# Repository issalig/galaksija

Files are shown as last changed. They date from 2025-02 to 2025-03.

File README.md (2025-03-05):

# galaksija
My building of Galaksija computer (thanks a lot Vlado Vince!)

- Case [(link)](https://github.com/issalig/galaksija/tree/main/case)
  - It contains scad files for the enclosure and the keys. [(base)](https://github.com/issalig/galaksija/blob/main/case/galaksija_case_base.stl) [(top)](https://github.com/issalig/galaksija/blob/main/case/galaksija_case_top.stl) [(keys)](https://github.com/issalig/galaksija/blob/main/case/galaksija_keys.stl)
  - The enclosure can be printed in 4 parts in order to fit in normal printers (aka Ender3)
  - Keys include also an stabilizer for space bar, you can print keys with letters on it or whithout it ans use stickers [(link)](https://github.com/issalig/galaksija/blob/main/case/galaksija_letters.pdf). Of course the script to generate it is available [(link)](https://github.com/issalig/galaksija/blob/main/case/galaksija_letters.py)
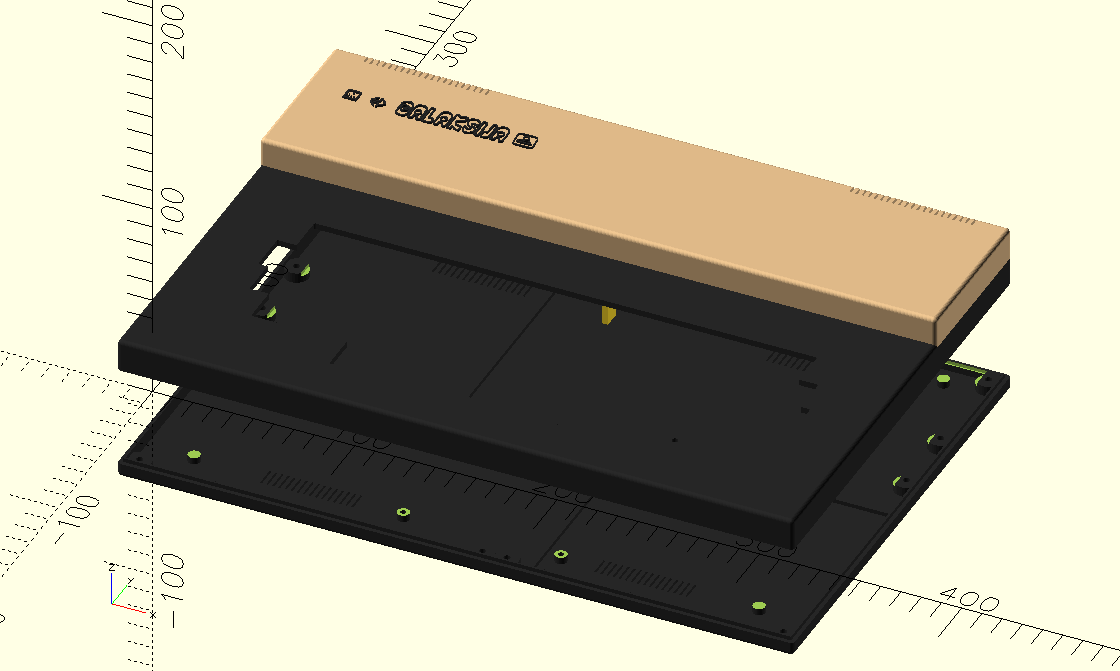
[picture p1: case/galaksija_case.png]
galaksija case
  
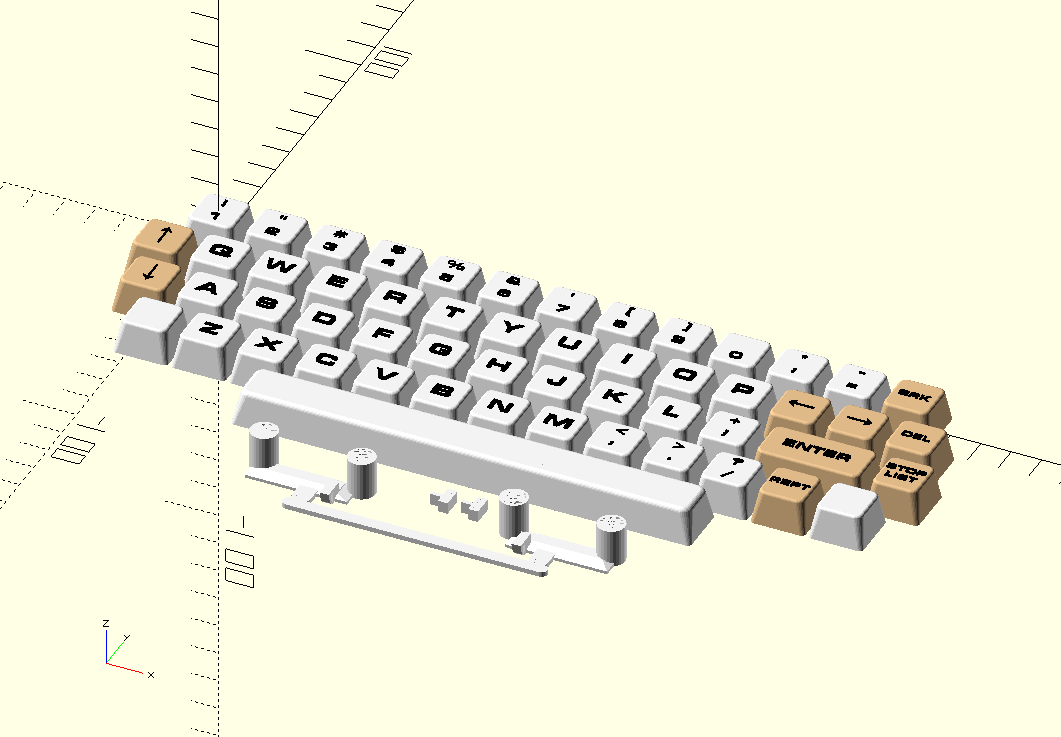
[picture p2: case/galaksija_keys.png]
galaksija keys
  
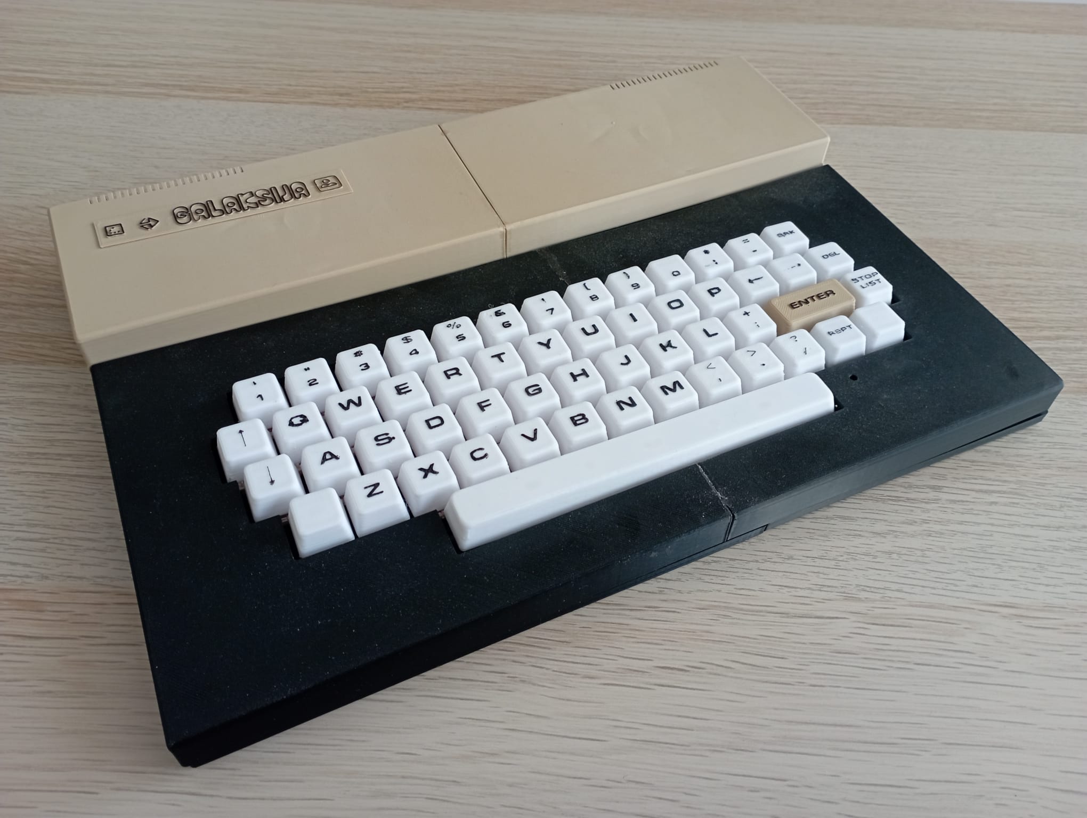
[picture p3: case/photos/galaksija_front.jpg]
galaksija front
  
  
- HW  [(link)](https://github.com/issalig/galaksija/tree/main/hw)
  - In order to build it follow instructions from https://github.com/mejs/galaksija
  - I have used v2 pcb which supports cherry switches (https://cdn.hackaday.io/files/6059259228256/Galaksija%20Outputs.zip) and you can get switches (70 pcs) from here (https://aliexpress.com/item/1005006396423418.html)
  - I use a Z80 that supports 20Mhz (not needed of course) Z84C0020PEC
  - I have used 27C512 for the ROMs instead of 2732 in a Manhattan style.
    - You just need add some wires like in the diagram and replicate the rom file.
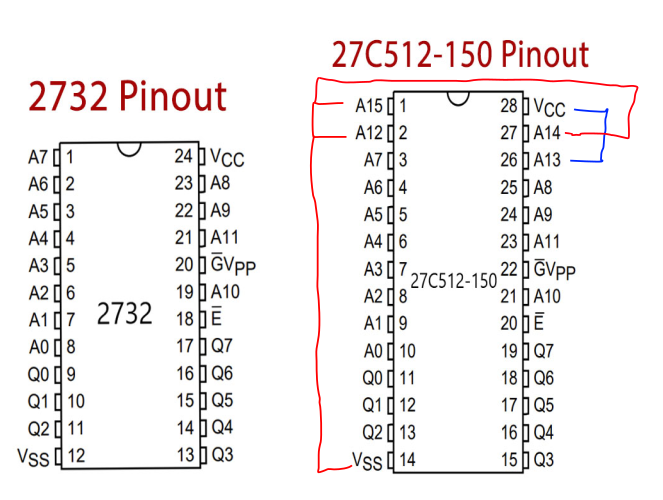
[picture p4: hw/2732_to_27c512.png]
adapter
    
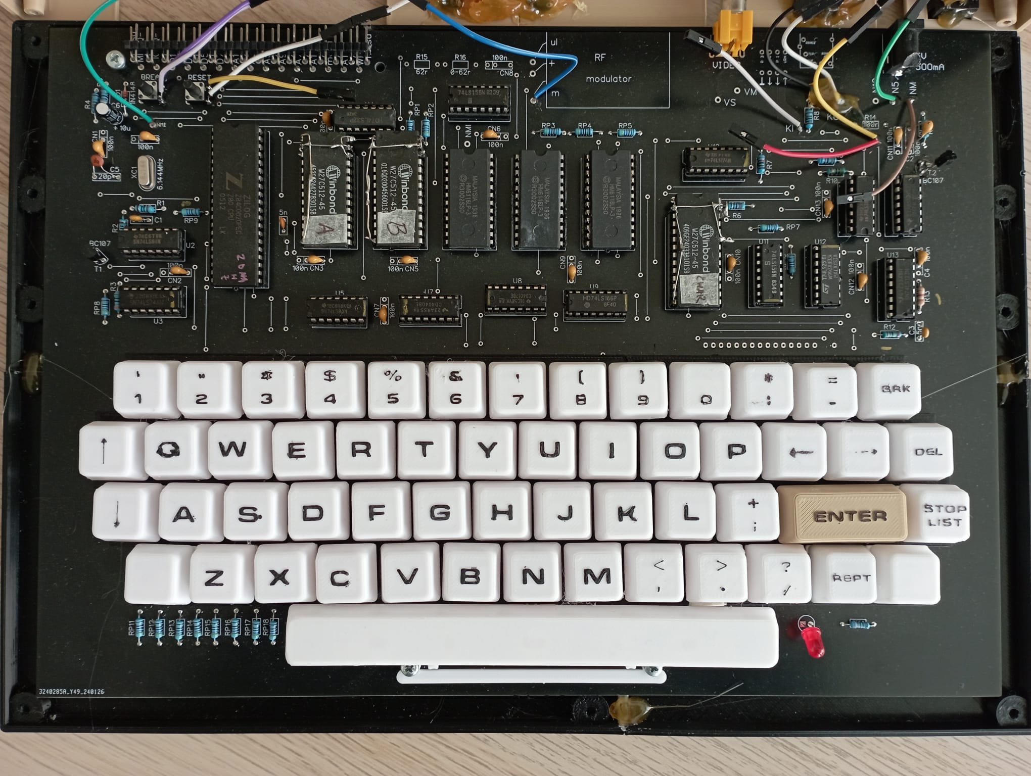
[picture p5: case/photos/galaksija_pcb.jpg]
pcb
    
    - Plan b: Get an adapter such as https://www.ukvac.com/forum/threads/2708-2716-2732-adapter-to-27512-eeprom.67258/
  - Get authentic ICs or you will have problems and a lot of "fun".
  - I have wired BRK, NMI and Reset and connected to buttons on the back side.
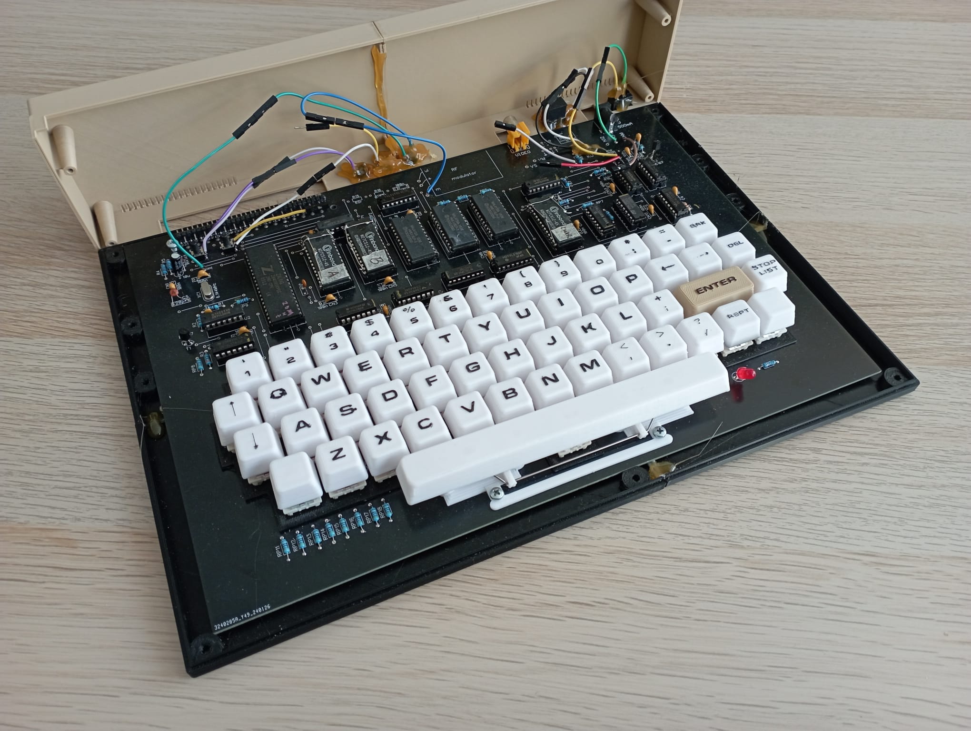
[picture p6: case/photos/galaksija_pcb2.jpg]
pcb2
    
  - Audio connections go to KI and KM
  - C2 is 1 uF (105)
  - Capacitor next to Z80 is 3.3 nF (332)

- ROMS [(link)](https://github.com/issalig/galaksija/tree/main/roms)
  - **Assembly** files for ROM A, B and C !!!!!
  - I am using ROM A [(v29 B autostart)](roms/original/ROM_A_with_ROM_B_init_ver_29.bin)
    - You can check it from your Galaksija with
      ```basic
      DUMP &0037,1
      1D (for version 29)
      DUMP &03F9,1
      CD 00 10 (call $1000 for version 29)
      ```
  - For ROM B, I use normal [(ROM_B)](roms/original/ROM_B.bin)
    - Check yours with
      ```basic
      DUMP &1024,1
      0C (for ROM B normal)
      ```          
  
- SW (TO-DO)
  - Document GTP format (WIP)
  - To load SW I got best results with a laptop. Mobile phone seem to have lower signal voltage and did not work.
 
- Other links
  - https://qsl.net/yt2fsg/galaksija/galaksija_clone.html
  - https://www.специалист-пк.рф/Galaksija/index6.html
  - https://8bitchip.info/galaksija/galaksija/schemes/GalaksijaPlus.pdf
  - https://emulator.galaksija.org/MagScans/index.html
  - https://github.com/YagoTudela/Galaksija_Plus/blob/main/SoundGenerator/SoundGeneratorPVV_01.png

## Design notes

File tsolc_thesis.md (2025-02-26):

This document is a transtlation from slovene to english from the thesis of Tomaž Šolc (https://web.archive.org/web/20240114192751/https://www.tablix.org/~avian/blog/papers/tomaz_solc_replika_mikroracunalnika_galaksija.pdf).

A presentation covering the topics of this thesis can be found in https://fahrplan.events.ccc.de/congress/2012/Fahrplan/attachments/2250_prezentacija.pdf

Another presentation in slovenian is found at https://web.archive.org/web/20230803180502/https://www.tablix.org/~avian/blog/articles/talks/mikroracunalnik_galaksija.pdf

---

# Replica of the Galaksija Microcomputer

**Tomaž Šolc**  
**Mentor:** Professor Dr. Tadej Tuma  

**University Diploma Thesis**  
**University of Ljubljana**  
**Faculty of Electrical Engineering**  

**Ljubljana, 2007**  

---

### **Abstract**  

Due to various reasons, a shortage or even complete absence of detailed documentation for older microprocessor systems is common today. Because of this, reverse engineering is often required, and understanding the design practices and methods from the era in which the system was created is essential for its success.  

**Galaksija** is a Yugoslavian home microcomputer from the 1980s, which holds historical significance. Due to its publication in magazines, part of the hardware documentation and a large collection of software, including the operating system, have been preserved to this day. As a typical yet relatively simple microprocessor system from that time, **Galaksija** provides an accessible insight into the design techniques used in that period.  

This thesis first reconstructs the documentation of **Galaksija**’s hardware architecture based on preserved schematics and reverse engineering of the software. This documentation is then used to design and build a **replica of Galaksija**—an electronic circuit built with modern components, which remains software-compatible with the original microcomputer and runs the original operating system.  

The creation of the replica also served as a foundation for documenting peculiarities in the implementation of the original electronic circuit. Furthermore, a working replica was used as a tool to analyze the programming techniques employed in the development of Galaksija’s operating system. The purpose of this documentation is to facilitate similar projects aimed at restoring microprocessor systems from this era.  

Additionally, this work includes the development of software tools for reverse engineering Z80 machine code and a development environment for the Galaksija architecture.  

**Keywords:** Galaksija, microcomputers, microprocessor systems, operating system, reverse engineering  

### **Acknowledgments**

I would like to express my gratitude to my mentor, Prof. Dr. Tadej Tuma, for his support in the preparation of this thesis.

I would like to thank my parents and my sister Barbara for their support and help during critical moments. My mother for her scientific perspective on the world and my father, who served as a role model for me in the study of electronics.

I would like to thank Mr. Jože Stepan for his assistance in gathering documentation and preserved articles about the Galaksija, for the creation of the printed circuit board, and last but not least, for the interesting conversations about old computer and electronic equipment.

I would also like to thank Tomaž Kac for his collection of preserved software for the Galaksija and for occasional hints during the exploration of the Galaksija's functionality.

I would like to thank Prof. Mateja Cvelbar for proofreading this work.

Finally, I would like to thank the other members of the Kiberpipa Computer Museum team, who allowed me access to the hidden parts of old computers and whose interest in the Galaksija was actually the reason for the creation of this thesis.

---

### **Index**
[1 Introduction](#1-introduction)
 - 1.1 Galaksija
 - 1.2 Motivation
 - 1.3 Objectives

[2 Hardware Architecture](#2-hardware-architecture)
 - 2.1 Use of Address Space
 - 2.2 Peripherals
 - 2.2.1 Keyboard
 - 2.2.2 Tape Interface
 - 2.2.3 Latch
 - 2.3 Control of the A7 Line for RAM
 - 2.4 Video Signal Generation
 - 2.4.1 Synchronization
 - 2.4.2 Character Generator
 - 2.4.3 Video Driver
 - 2.4.4 Shift Register

[3 New Galaksija](#3-new-galaksija)
 - 3.1 Digital Section
 - 3.1.1 Microprocessor and Memory
 - 3.1.2 Address Decoder
 - 3.1.3 Keyboard
 - 3.1.4 Clock Divider
 - 3.1.5 Shift Register
 - 3.1.6 Interrupt Synchronization
 - 3.2 Analog Section
 - 3.2.1 Power Supply
 - 3.2.2 Oscillator
 - 3.2.3 Reset Circuit
 - 3.2.4 Composite Video
 - 3.2.5 Tape Interface

[4 Specifics of the Original Galaksija Circuit](#4-Specifics-of-the-Original-Galaksija-Circuit)
 - 4.1 Use of Undocumented Microprocessor Features
 - 4.1.1 First Memory Cell
 - 4.1.2 Second Memory Cell
 - 4.2 Microprocessor Bus Wiring
 - 4.3 Keyboard Wiring
 - 4.4 Use of the R Register

[5 Specifics of the Operating System](#5-specifics-of-the-operating-system)
 - 5.1 Multilingual Program Code
 - 5.2 Multilingual Data Structures
 - 5.3 Organization of Program Code
 - 5.4 Use of Processor Registers
 - 5.5 Processor Stack
 - 5.6 Storing Data on Tape

[6 Conclusion](#6-conclusion)

[Bibliography](#bibliography)

[Appendix](#appendix)
 - A Voltage Inverter
 - B Calculation of the Pulse Amplifier
 - C Floating-Point Numbers

## **1. Introduction**
[Up](#Replica-of-the-Galaksija-Microcomputer) [Previous](#Index) [Next](#2-hardware-architecture)

### **1.1 Galaksija**

**Galaksija** is a home microcomputer designed in 1983 by **Voja Antonić**. Similar to other microcomputers developed in former Yugoslavia at the time, **Galaksija** was intended as a domestic alternative to foreign microcomputers produced by **Sinclair Research** (Sinclair ZX81, Sinclair ZX Spectrum) and **Commodore Business Machines** (Commodore 64). These foreign microcomputers, although highly sought after, were difficult to obtain legally due to strict import restrictions on Western technology and their relatively high prices[^1].

To make the computer as affordable as possible and accessible to the widest range of people, its electronic circuitry was designed to be as simple as possible, including only components that were either readily available in electronic stores at the time or could be easily imported from neighboring countries. Since cost reduction was the highest priority in its design, many compromises had to be made in hardware. For example, the computer's operation depends on certain undocumented features of the microprocessor, along with other design choices that would be unacceptable in modern systems. The development of system software was also heavily influenced by the goal of keeping hardware costs low.

A comparison of **Galaksija**’s capabilities with similar foreign and domestic microcomputers from the same era is shown in **Tables 1 and 2**.

Initially, **Galaksija** was intended for self-assembly. To facilitate this, the designer, with the assistance of editor **Dejan Ristanović**, published a complete guide on how to build it in a **special edition of the magazine Galaksija**, released in January 1984 [^2]. This publication, which included a significant portion of the development documentation, ensured that much of the technical details were preserved. Due to high demand, the computer was later produced as a commercial product as well.

imagen

Figure 1: Handmade Galaksija prototype (private collection of Damjan Lenarčič).

imagen

Figure 2: Factory-produced Galaksija (manufactured by Zavod za udžbenike i nastavna sredstva).

imagen

Figure 3: Top view of the original Galaksija PCB (private collection of Iztok Pušnar).

imagen

Figure 4: Bottom view of the original Galaksija PCB (private collection of Iztok Pušnar).

#### **Table 1: Comparison of Galaksija with foreign microcomputers**  

| Feature | ZX81 (1981) | Galaksija (1984) | ZX Spectrum (1982) | Commodore 64 (1982) |
|---|---|---|---|---|
| **CPU** | Zilog Z80A | Zilog Z80A | Zilog Z80A | MOS 6502 |
| **Clock Speed** | 3.25 MHz | 3.072 MHz | 3.5 MHz | 0.985 MHz (PAL) |
| **ROM** | 8 KB | 4 KB (ROM A) | 16 KB | 20 KB |
| **RAM** | 1 KB | 2, 4, or 6 KB | 16 or 48 KB | 64 KB |
| **Video Output** | Software-based | Software-based | Dedicated IC (ULA) | MOS VIC-II |
| **Resolution** | 32×24 chars | 32×16 chars | 32×24 chars | 40×25 chars |
| **Graphics Mode** | 64×48 pixels | 64×48 pixels | 256×192 pixels | 320×200 pixels |
| **Color Support** | No | No | 15 colors | 16 colors |
| **Sound** | No | No | Software-based | MOS SID |

#### **Table 2: Comparison of Galaksija with other Yugoslavian microcomputers**  

| Feature | Galaksija | Orao | Lola-8 | Galeb |
|---|---|---|---|---|
| **CPU** | Zilog Z80A | MOS 6502 | Intel 8085A | MOS 6502 |
| **Clock Speed** | 3.072 MHz | 1 MHz | 5 MHz | No data |
| **ROM** | 4 KB (ROM A) | 16 KB | 16 KB | 16 KB |
| **RAM** | 2, 4, or 6 KB | 8 KB | 6 KB | 9 KB |
| **Resolution** | 32×16 chars | 32×16 chars | 40×25 chars | 48×16 chars |
| **Graphics Mode** | 64×48 pixels | 256×128 pixels | 80×75 pixels | 96×48 pixels |
| **Color Support** | No | No | No | No |
| **Sound** | No | Yes | Yes | Yes |

### **1.2 Motivation**

Due to the rapid advancement of computer technology, knowledge required for maintaining older systems is being lost at an increasing rate. This phenomenon is particularly evident in consumer electronics, where products can become obsolete and disappear from manufacturers' public archives within a year or less. Frequent company mergers and restructurings further worsen the situation by adding more barriers to accessing archival documentation.

At the same time, consumer electronics are increasingly replacing expensive, specialized industrial equipment due to their affordability and widespread availability. The most significant examples of this trend are personal computers, where mass production enables manufacturers to invest heavily in development. As a result, even computer architectures originally designed for relatively simple personal computing have outperformed certain specialized architectures.

A common problem that arises in practice is that **software often has a much higher value than the hardware it runs on**. This is particularly true in highly reliable systems, where software has been improved over time through use and bug fixes, making it significantly more reliable than newly developed alternatives. While software does not physically deteriorate, hardware requires occasional maintenance. When maintenance costs become too high, it makes sense to develop a new, **compatible** hardware system. However, due to the reasons mentioned earlier, documentation for the original hardware is often unavailable. In such cases, **reverse engineering** is required to recreate the missing documentation.

The **Galaksija microcomputer** provides an excellent example of the design approaches used by both hardware and software developers in the 1980s. While Galaksija itself was not widely used for professional purposes, the experience gained from reverse engineering it can be applied to similar projects with greater practical value.

Building a **replica of Galaksija** also serves an important role in preserving **technical heritage**. Due to advancements in microelectronics, the **original integrated circuits required to build a new Galaksija are no longer available**. As a result, only a limited number of **functional Galaksija computers** remain, restricting the ability to run historical software. The Galaksija system and its software are historically significant as they contributed to the spread of computer knowledge and literacy in **former Yugoslavia**.

Additionally, teaching the **fundamentals of microprocessor systems** often faces the challenge that modern systems are **too complex** to serve as simple educational examples. For instance, the architecture of a modern **PC** is so intricate that a student cannot realistically understand all its components. Furthermore, manufacturers often **intentionally obscure** internal workings to maintain a competitive advantage. The high level of **integration** in modern electronics also prevents direct observation of internal circuits using standard laboratory instruments.

In contrast, **Galaksija** is made up of relatively **simple electronic circuits**, built from **low- and medium-scale integrated circuits** (with the exception of the **Z80 microprocessor**, for which detailed documentation is available). Additionally, the system's **low clock speed** allows for analysis using **affordable oscilloscopes**. Despite its simplicity, Galaksija remains a **fully functional microprocessor system**, containing the same core components as modern computers (CPU, memory, bus, peripherals, etc.).

### **1.3 Objectives**

The main objectives of this work are:  

- To **describe the functionality of Galaksija’s hardware** (and software components closely related to hardware) in sufficient detail so that a new **compatible** computer can be built based on this description.  
- To **construct a fully functional replica** of **Galaksija**, using **modern electronic components** available on today’s market, while maintaining similarity to the original where practical.  
- To **document the design techniques** used in the original system, making it easier to restore **other** microcomputer systems from the **1980s**.  

## **2. Hardware Architecture**
[Up](#Replica-of-the-Galaksija-Microcomputer) [Previous](#1-introduction) [Next](#3-new-galaksija)

The block diagram of the **Galaksija** motherboard is shown in **Figure 5**. A facsimile of the original circuit diagram【2】is included in the appendix.

imagen

Figure 5: Block diagram of Galaksija motherboard.

### **2.1 Address Space Utilization**

The **Z80 microprocessor**【6】has **two separate address spaces**:  

1. A **16-bit address space** for memory  
2. An **8-bit address space** for input/output (I/O) operations  

The **Galaksija motherboard** only utilizes the **memory address space**, both for **memory access** and for **communication with peripherals** (a technique known as **memory-mapped I/O**).

imagen

Figure 6: Galaksija’s memory map and address space allocation.

**Figure 6** illustrates the memory **layout** and how memory and peripheral devices are mapped into the address space (**memory map**). This layout is defined by the **address decoder circuit** and **cannot be changed via software** (except for control of the **A7 address line for RAM**, as shown in **Figure 9**). Unused parts of the address space are **reserved for future expansion**, and reading from these addresses returns **undefined values**.

The **4 KB read-only memory (ROM A)**, which contains the **system software**, is mapped at address **0x0000** and occupies the **interrupt vectors** of the microprocessor. Another **4 KB read-only memory (ROM B)** is mapped at address **0x1000** and is reserved for **expansion**.

Writing to memory addresses used by the **ROM** is **not allowed**. On computers **without ROM B**, reading from addresses mapped to it returns **undefined values**.

At **0x2800**, **2 KB to 6 KB of static RAM (SRAM)** is mapped. This RAM does **not require refresh cycles** using the **memory refresh counter** of the **Z80 processor**.

The entire **I/O address space** is reserved for **expansion**, and reading from **unmapped** I/O addresses returns **undefined values**.

imagen

Figure 7: Keyboard memory address mapping.

### **2.2 Peripherals**

The **processor accesses peripherals** through a **2 KB block** of the **memory address space**, starting at **0x2000**.

imagen

Figure 8: Latch register bit layout.

#### **2.2.1 Keyboard**

The keyboard has **54 keys**, each of which is mapped to a **specific address in memory**, as shown in **Figure 7**. The exception is the two **SHIFT** keys, which from the software perspective behave as a single key. This key is considered pressed if either of the physical **SHIFT** keys is pressed.  
The base memory address for the keyboard is **0x2000**, with multiple address offsets for different keys. Due to **incomplete address decoding**, the **keyboard can be accessed from 32 base addresses** (e.g., 0x2000, 0x2040, …, 0x27C0). **Unused memory locations** behave as if **no key is pressed**.

If the **least significant bit (LSB)** at a specific **keyboard address** is **0**, the key is **pressed**. If the bit is **1**, the key is **not pressed**. The **other bits** in the address return **undefined values**.

Writing to the **keyboard memory addresses** is **not allowed**.

imagen

Figure 9: A7 line control for RAM address remapping.

#### **2.2.2 Cassette Interface**

The **cassette interface** consists of an **analog input** and an **analog output**.

- The **analog input** is implemented as a **simple comparator** with a **high-pass filter** at the input.  
- If a pulse with an **amplitude greater than approximately 700 mV** (determined by the transistor **T2**) appears at the input, the **least significant bit (LSB)** at the **comparator addresses** in **Figure 7** is set to **0** for the duration of the pulse.  
- The **maximum pulse length** is defined by the **filter** consisting of **C2** and **R14**. The cutoff frequency of the filter, according to published data [2], is approximately **16 kHz**, which is too high considering the frequency response of an average audio cassette recorder. I conclude that this is likely a printing error.  

The **analog output** is controlled through **two bits** in the **latch register** (**Figure 8**, **AOUT0 and AOUT1**), forming a **simple digital-to-analog converter (DAC)**. The output voltage is determined by the states of these two bits, as shown in **Table 3**.

| **AOUT0** | **AOUT1** | **Output Voltage (Ua) [V]** |
|---|---|---|
| 0 | 0 | 0.0 V |
| 1 | 0 | 0.5 V |
| 0 | 1 | 0.5 V |
| 1 | 1 | 1.0 V |

**Table 3:** Analog output voltage levels for tape interface.

The functions of the **individual bits** in the latch register are given in **Table 4**:

| **Bit** | **Description** |
|---|---|
| A7CLMP | If this bit is set to 0, the address line A7 for RAM memory is set to 1, regardless of the value on the processor's address bus. See Figure 9. |
| AOUT0-1 | Control of the digital-to-analog converter (DAC) for the tape interface. |
| CHR0-3 | Control of the current row (scanline) being displayed by the character generator. |

**Table 4:** Meanings of individual bits in the latch register.

### 2.2.3  **Latch**  

The microprocessor can access a **6-bit register** (referred to as the "latch" in the original documentation) at addresses of the form **0x0010 0xxx xx11 1xxx** (the lowest such address is **0x2038**, and the highest is **0x27FF**). This register is used to control the character generator, the analog output, and the **A7** address line for the RAM memory.  

- **Writing:** Only 8-bit values can be written to these addresses.  
- **Reading:** Reading from these addresses returns an undefined value.  

The meanings of the individual bits (labeled in Figure 8) are provided in **Table 4**.  

### **2.3 A7 Address Line Control for RAM**

Setting the **A7CLMP bit** allows the **A7 address line** of RAM to be **forced to 1**, regardless of the address bus value from the processor. This allows the **processor to read values stored in odd-numbered 128-byte blocks**, even when accessing even-numbered addresses.

This feature is used in **video signal generation** due to a **peculiarity of the Z80 processor**, which **does not automatically increment the A7 line** during **memory refresh cycles**【6】.

### **2.4 Video Signal Generation**

**Galaksija** is designed to be connected to a **composite video monitor** or a **TV via a UHF modulator**. In both cases, the display uses a **cathode-ray tube (CRT)**, so the following descriptions rely on the **movement of the electron beam** across the screen.

Due to the **simple hardware design**, **video signal generation** requires **active cooperation from the microprocessor**. Proper **synchronization** of software execution with the **movement of the electron beam** is essential.

The **video driver** responsible for generating the video signal is located in **ROM A at address 0x0038**, which is the **interrupt vector for the INT interrupt** in **interrupt mode IM 1**.

### 2.4.1  **Synchronization**  

The fundamental timing intervals important for generating the video signal are shown in **Figure 10**. The microprocessor's clock (3072 kHz) and the video signal circuit's clock (6144 kHz) are synchronized. The screen area is divided into a black border, which is not usable for displaying images, and the usable area in the center. Drawing one row on the screen always takes **128 microprocessor clock cycles**, and the entire usable area consists of **208 rows**. Horizontal and vertical synchronization pulses are generated by hardware.  

imagen

Figure 10: Video synchronization timing.

When the electron beam begins moving to the start of the first row of the visible screen area at the **56th horizontal synchronization pulse**, the video circuit interrupts the execution of the user program via an **INT interrupt**.  

The delay in the microprocessor's response to the interrupt is **non-deterministic**. It depends on the time the processor needs to complete the execution of the current instruction, which can range from **1 to 23 clock cycles**. However, since the video driver code must execute in perfect synchronization with the beam's movement across the screen, the microprocessor's execution is halted for the duration of one screen row (**192 clock cycles**) after responding to the interrupt. This is achieved by inserting a specific number of **HALT states** into the processor's operation, implemented via a circuit connected to the processor's **WAIT signal**. See **Figure 11**.  

imagen

Figure 11: Processor timing during video signal generation.

#### **2.4.2 Character Generator**

The information about the screen image is stored in a 512-byte section of RAM memory at address 0x2800. This section contains ASCII codes of characters (16 rows of 32 characters each) that are displayed on the screen with each screen refresh. The task of the video driver, which runs on the microprocessor during the refresh, is to sequentially read 8-bit ASCII codes from this memory section and transfer them to the character generator.

The character generator is a 2 kB ROM (character generator ROM) that stores the mapping from the ASCII code of a character to its corresponding bitmap representation (i.e., the pattern of dots that form the character on the screen). The way a character is stored is shown in Figure 12. Bit 0 in the bitmap represents a bright dot on the screen, while bit 1 represents a dark dot.

imagen

Figure 12: ASCII character ROM encoding structure.

The lower 7 address lines of the ROM are connected to the microprocessor's data bus, while the upper 4 lines are connected to bits CHR0 to CHR3 in the latch. This allows the processor, by setting the latch and placing values on the data bus (e.g., by reading values from RAM), to retrieve any scanline of any character from the character generator.

imagen
imagen

Figure 13: Galaksija’s character set table.

Figure 13 shows all 128 characters that the character generator can display on the screen. Since the D6 line of the data bus is not connected, each stored character corresponds to two 8-bit ASCII codes. The arrangement of characters is chosen so that the codes of the first 64 characters overlap with the central half of the standard ASCII character set (ASCII codes 20 to 5F). The remaining 64 characters consist of a set of pseudographic symbols, enabling a graphical display resolution of 64x48 pixels.

On the screen, each character is composed of 13 rows (13 · 16 = 208). The video driver in the ROM uses only the first 12 scanlines out of the 16 stored in the ROM. The 13th scanline of each character is always blank (black) on the screen because, during the time the electron beam scans this line, the video driver prepares to draw the next row of characters, and the character generator is disabled.

It is also important to note that the last scanline (address 0x0F) of all stored characters is blank (contains all ones). This line is set in the latch while the user's program is running. This ensures that the character generator is disabled when the content on the microprocessor's data bus is not under the direct control of the video driver. This also ensures that the beam intensity is minimized while the beam scans the black border of the screen and during the beam's diagonal retrace to the starting point.

#### **2.4.3 Video Driver**

The video driver must ensure that, as the electron beam scans the usable area of the screen, a byte corresponding to the ASCII code of the character to which the next 8 pixels belong appears on the data bus every 4 clock cycles (3072 kHz).

The sequential reading of the video memory section is implemented using a Z80 microprocessor function [6], which is otherwise intended for refreshing dynamic memory. The driver, just before starting to draw a screen scanline, sets the microprocessor's I and R registers so that they form a pointer to the memory location where the beginning of the 32-character row is located. The microprocessor's internal logic then ensures that, during program execution, 1 byte is read from memory and the R register is incremented with each M1 cycle.

To meet the requirement of transferring one byte every 4 clock cycles, the video driver must execute (any) 32 processor instructions that have only one M cycle (i.e., they consist only of an M1 cycle and last 4 clock cycles). After 32 M cycles, the current row is drawn, and the video driver can prepare to draw the next row while the beam scans the screen border.

Before drawing each scanline, the CHRx bits in the latch must be correctly set to specify the current scanline number in the character generator. After drawing, the character generator is disabled by selecting scanline 0x0F.

The microprocessor itself does not increment the I register or the highest bit of the R register. The driver sets the I register programmatically while preparing to draw a new row, and the highest bit of the R register is set together with the selection of the scanline via the A7CLMP bit in the latch.

imagen

Figure 14: Video driver execution flowchart.

Figure 14 shows a simplified diagram of the video driver's execution. The diagram does not show the driver code required for synchronizing memory reads with the electron beam, setting the A7 line, and writing the current scanline number to the latch.

#### **2.4.4 Shift Register**

The output of the character generator is connected to a parallel/serial shift register. This register loads 8 bits from the character generator at the right moment and serially sends them to the video output over 8 video clock cycles (6144 kHz). The serial loading occurs at the end of each M1 cycle of the microprocessor (Figure 15).

imagen

Figure 15: Timing of the shift register during video output.

While the video driver is active and the beam scans the usable area of the screen, the shift register sequentially loads character bitmaps during M1 cycles. However, when the user's program is running, blank (dark) scanlines 0x0F are loaded into the register. This ensures that no random values from the data bus appear in the video signal during synchronization pulses and while the beam scans the black border of the screen.

When executing instructions that have multiple M cycles (and thus last more than 4 processor clock cycles), the shift register is completely emptied (since more than 8 video clock cycles pass between two parallel loads). The serial input of the register is therefore connected to a logical 1. This ensures that nothing is displayed on the screen during the execution of longer processor instructions in the user's program.

# **3. New Galaksija**
[Up](#Replica-of-the-Galaksija-Microcomputer) [Previous](#2-hardware-architecture) [Next](#4-Specifics-of-the-Original-Galaksija-Circuit)

The electronic circuit of the new Galaksija is largely similar to the original. However, certain parts have been modified due to the unavailability of equivalent components, making it impossible to implement them exactly as per the original design. During the design of the replica, **reliability of operation** was prioritized over manufacturing cost. As a result, all known shortcomings of the original circuit were addressed, provided that such fixes would not be detectable from a software perspective. The new circuit has also been adapted for easier connection to modern television receivers or monitors.  

The wiring diagram of the circuit and the printed circuit board (PCB) layout are included in the appendix.  

## **3.1 Digital Section**

The **digital components** in the **new Galaksija** are built using **high-speed CMOS logic (74HC series).**

### **3.1.1 Microprocessor and Memory**

The role of the central processing unit (CPU) in the new circuit is fulfilled by the **Z84C0008** integrated circuit from Zilog. This is a microprocessor manufactured in CMOS technology in a DIP40 package, which is fully hardware- and software-compatible with the **Z80** microprocessor used in the original Galaksija.  

The **read-only memory (ROM)** (U2) is implemented using a single **32 kB EPROM** (27C256) in CMOS technology. The modern chip used here has sufficient capacity to store both the basic operating system and its first extension (thus, this integrated circuit occupies both the **ROM A** and **ROM B** positions in the microprocessor's address space, as shown in Figure 6). The upper **24 kB** of the memory remains unused.  

Due to the implementation of the address decoder, the EPROM is enabled (outputs in a low-impedance state) even when the microprocessor attempts to write to the portion of the address space occupied by the EPROM. In this case, two devices with low-impedance outputs would be connected to the data bus, potentially causing a short-circuit current that could damage the microprocessor or the EPROM. To limit the current in such cases, resistors **R10-R17** are placed between the EPROM's data lines and the data bus.  

The **working memory (RAM)** (U3) consists of an **8 kB SRAM** chip (LH5164D). The lower **2 kB** of the memory is unused (this portion of the address space is occupied by peripherals).  

| **Component** | **Type** | **Function** |
|---|---|---|
| **CPU (U1)** | Zilog Z84C0008 | CMOS version of Z80, fully compatible |
| **ROM (U2)** | 27C256 (32 KB EPROM) | Stores **ROM A**, **ROM B**, and additional space for expansions |
| **RAM (U3)** | LH5164D (8 KB SRAM) | Stores program variables and system memory |

imagen

imagen

imagen

**Figures 16, 17, 18**: Show the **motherboard, keyboard, and full enclosure** of the new Galaksija.

🔹 **Important modification**:  
- In the **new design**, the **EPROM remains active during write attempts**.  
- To **prevent short circuits**, **resistors (R10-R17)** limit current flow between the CPU and the EPROM.

### **3.1.2 Address Decoder**

The address decoder is composed of a dual **2/4 demultiplexer (U10)** and logic gates **(U18)**. It implements the addressing of the **EPROM**, **SRAM**, and peripherals in accordance with Figure 6.  

The addresses for the keys, comparator, and latch in the address space are a result of the keyboard matrix wiring, the demultiplexer **U7**, and the multiplexer **U6**.  

### **3.1.3 Keyboard**  

The new Galaksija features a keyboard on a separate printed circuit board (PCB), connected to the mainboard via a **20-pin connector**.  

The keyboard of the original Galaksija required open-collector outputs from the demultiplexer for its operation. Since the demultiplexer **U7** used here does not have such outputs, they are simulated by connecting diodes **D1** to **D7**.  

The output of the multiplexer is protected against short circuits with resistor **R30**, for similar reasons as the EPROM outputs.  

### **3.1.4 Clock Divider**  

The clock divider consists of **4 4-bit ripple counters** in circuits **U12** and **U13**. These counters derive the necessary signals for generating the composite video from the oscillator signal with a frequency of **6144 kHz**, according to the following equations:  

$$f_{\text{video}} = f_{\text{osc}} = 6144 \, \text{kHz}$$  
$$f_{\text{cpu}} = \frac{f_{\text{osc}}}{2} = 3072 \, \text{kHz}$$  
$$f_{\text{hsync}} = \frac{f_{\text{osc}}}{12 \cdot 16 \cdot 2} = 16 \, \text{kHz}$$
$$10 \cdot f_o = \frac{f_{\text{osc}}}{12 \cdot 16 \cdot 16 \cdot 4} = 500 \, \text{Hz}$$  

Using the **10 · f₀** signal, the **Johnson counter (U14)** generates two phase-shifted signals with a frequency of **f₀ = 50 Hz** (the signal for processor interrupts and vertical synchronization pulses) in accordance with the requirements for generating a composite video signal (Figure 11).  

| **Signal** | **Frequency Calculation** | **Result** |
|---|---|---|
| **Processor Clock** | \( f_{cpu} = \frac{f_{osc}}{2} \) | 3.072 MHz |
| **Horizontal Sync** | \( f_{hsync} = \frac{f_{osc}}{12 \times 16 \times 2} \) | 16 kHz |
| **Interrupt Frequency** | \( f_o = \frac{f_{osc}}{12 \times 16 \times 16 \times 4} \) | 50 Hz |

**Table 5**: *Comparison of Galaksija's video signal characteristics with the PAL B,G standard.*

With the help of the 10 · f₀ signal, the Johnson counter U14 generates two phase-shifted signals with a frequency of f₀ = 50 Hz (the signal for processor interrupts and vertical synchronization pulses) in accordance with the requirements for generating a composite video signal (Figure 11).

| **Characteristic** | **PAL B,G (Used in Slovenia)** | **Galaksija** |
|---|---|---|
| **Number of scanlines per frame** | 625 | 320 |
| **Field rate** | 50 Hz | 50 Hz |
| **Horizontal frequency** | 15.625 kHz | 16.000 kHz |
| **Interlacing** | 2:1 | 1:1 |
| **Black level** | 0 IRE | 0 IRE |
| **White level** | 100 IRE | 100 IRE |
| **Sync level** | -43 IRE | -43 IRE |
| **Nominal bandwidth** | 5 MHz | 3 MHz |

Even though **Galaksija’s horizontal frequency and number of scanlines differ from PAL standards**, most **TVs and monitors** can still **display its video signal correctly**.

### **3.1.5 Shift Register**

The logic circuit, composed of the gate U17, detects the fourth T state of the M1 cycle and triggers the parallel loading of data into the shift register U6 (Figure 19).

In the new circuit, the loading of data into the shift register occurs two video clock cycles earlier than in the original circuit (compare with Figure 15). The reason for this change is improved reliability (page 43), but the consequence is that the image is shifted two pixels to the left compared to the original Galaksija.

imagen

**Figure 19**: *Timing diagram of the shift register control circuit.*

### **3.1.6 Interrupt Synchronization**

A sequential logic circuit, composed of the memory cell U21 and the gates U19, detects the microprocessor's response to an interrupt and halts the execution of the first instruction of the video driver until the next horizontal synchronization pulse (Figure 20).

imagen

**Figure 20**: *Timing diagram of the interrupt synchronization circuit.*

## **3.2 Analog Section**

### **3.2.1 Power Supply**

To power the computer from the 240V AC mains voltage, an external 12V DC adapter with a power rating of 5W is used. On the motherboard, the 12V DC voltage is further converted into +5V and −5V supply voltages.

    The +5V voltage is used to power all digital and analog components and is obtained using the voltage regulator U9.

    The −5V voltage is used to power the video amplifier and is obtained using a switching voltage inverter and the voltage regulator U22 (see Appendix, page 63).

| **Power Supply** | **Voltage** | **Function** |
|---|---|---|
| **External Adapter** | +12V DC | Provides input power |
| **Internal Regulator (U9)** | +5V DC | Powers **digital components** |
| **Voltage Inverter (U22)** | -5V DC | Powers **video amplifier** |

- The **-5V supply** is generated by a **switching voltage inverter (U22)**.

### **3.2.2 Oscillator**

A crystal oscillator generates the base clock signal with a frequency of 6144 kHz. The active part of the oscillator consists of the logic gate U19.

### **3.2.3 Reset Circuit**

The reset circuit keeps the processor in a reset state for a short period after power is turned on. This ensures that, by the time the operating system starts, any transient phenomena in the supply voltages have subsided, which could otherwise cause operational errors.

### **3.2.4 Composite Video Output**

From the clock signals generated by the clock divider, the horizontal and vertical synchronization pulses are generated using two monostable multivibrators (circuit U15). These pulses are then combined into a composite synchronization signal using an XOR logic function implemented by the logic gate U16.

The synchronization signal and the video signal from the shift register are then fed into a mixer (Q4, Q5). The resistors R21 and R22 determine the ratio between the synchronization signal and the black level.

The resulting composite video signal is first passed through a resistive divider (R24, R27) to adjust the signal amplitude, and then into a two-stage amplifier in a common-collector configuration (Q6, Q8). The generated signal has a peak-to-peak voltage of 2V with an output impedance of 75Ω.

imagen

**Figure 21**: *Bode plot of the video amplifier (SPICE simulation).*

Calculation of Video Signal Bandwidth [8][9]:  

The bandwidth of the video signal is calculated as follows:  

$$BW = \frac{1}{2} \cdot K \cdot N_{ht} \cdot N_{vt} \cdot f_o \cdot K_h \cdot K_v$$

Where:  
- \( K \) is the Kell factor,  
- \( N_{ht} \) and \( N_{vt} \) are the horizontal and vertical screen resolutions,  
- \( f_o \) is the frame rate (50 Hz),  
- \( K_h \) and \( K_v \) are the fractions of time occupied by horizontal and vertical synchronization.  

Substituting the values:  

$$BW = \frac{1}{2} \cdot 0.7 \cdot 256 \cdot 208 \cdot 50 \, \text{Hz} \cdot \frac{64 + 256 + 64}{256} \cdot \frac{56 + 208 + 56}{208} = 2.2 \, \text{MHz}$$  

From the graph in Figure 21, we can see that the amplifier has sufficient bandwidth and exhibits approximately **0.5 dB of linear distortion** in the frequency range covered by the video signal.  

### 3.2.5  **Tape Interface**  

The analog output of the tape interface uses a simple digital-to-analog converter (DAC), similar to the original Galaksija. The output voltages depend on the resistors **R25**, **R26**, and **R28**.  

Figure 22 shows a recording of the output signal (in this case, one synchronization byte) made with an analog-to-digital converter at a sampling frequency of **44.1 kHz**.  

The analog input consists of a pulse amplifier that acts as a simple analog-to-digital converter. The circuit topology is the same as in the original Galaksija, but the component values have been recalculated (see Appendix, page 65) due to an error in the original design.  

An example of the input and output signals of the amplifier for a single input pulse is shown in Figure 23.  

imagen

**Figure 22**: *Output waveform of the cassette interface (measured).*  

imagen

**Figure 23**: *Input and output waveform of the impulse amplifier (SPICE simulation).*

### 4 **Specifics of the Original Galaksija Circuit**  
[Up](#Replica-of-the-Galaksija-Microcomputer) [Previous](#3-new-galaksija) [Next](#5-Specifics-of-the-Operating-System)
#### 4.1  **Use of Undocumented Microprocessor Features**  

The original Galaksija has two **D flip-flops** (in the 74LS74 integrated circuit) in its electronic circuit, which are used to detect the state of the microprocessor:  
- The first flip-flop detects the **interrupt request/acknowledge cycle** and is involved in the video synchronization circuit (page 23).  
- The second flip-flop detects the end of the **M1 cycle** and controls the loading of data into the video shift register (page 30).  

In both cases, proper operation depends on the **minimum delays** of certain output signals of the Z80 microprocessor, which are **not guaranteed** by the manufacturer in the documentation. This approach was most likely chosen to save on the number of components on the printed circuit board, as more reliable implementations would require at least one additional integrated circuit.  

The signal delays critical for the correct operation of the original Galaksija circuit depend on variations in the manufacturing of the microprocessor integrated circuit. Typically, delays within a single batch of circuits are similar, but they can vary significantly between batches (within the tolerances specified by the manufacturer).  

This circuit characteristic is one of the main factors preventing the construction of Galaksija according to the original plans. With modern CMOS integrated circuits, which are otherwise equivalent to the original NMOS circuits according to the manufacturer's specifications, the circuit does not function correctly because the delays in modern circuits are significantly shorter than in the original ones (specifications in most cases only provide maximum values for certain delays).  

The Galaksija replica resolves this issue at the cost of a more complex circuit.  

**Table 6**: *Comparison of undocumented timing characteristics across Z80 variants.*

| **Z80 Variant** | **Typical M1 Delay** | **Maximum M1 Delay** |
|---|---|---|
| **Original NMOS Z80 (Z8400, 4 MHz)** | ~100 ns | 250 ns |
| **CMOS Z80 (Z84C0008, 8 MHz)** | ~50 ns | 150 ns |
| **Modern Z80 Clones** | Varies | Undefined |

The **timing difference** between **old NMOS** and **modern CMOS** Z80s is the **main reason why original Galaksija designs do not work properly with modern processors**.

### 4.1.1  
**First Memory Cell**  

In the third **T state** of the interrupt cycle, a logical **0** must be written to this memory cell. For this purpose, the **D input** of the cell is connected to the **/M1 line** of the microprocessor, and the clock signal of the cell is connected to **/IORQ**. From **Figure 24**, it is evident that for proper operation, the clock signal of the cell must have a positive edge while the **D signal** is still at a logical **0**.  

imagen

**Figure 24:** Timing diagram of the operation of the first D flip-flop from the perspective of the microprocessor signals (response times shown are for the 4 MHz NMOS version of the Z8400 integrated circuit [10]).  

However, the microprocessor manufacturer only guarantees **maximum timing intervals** between the positive edge of the processor clock and the transitions of the **/M1** and **/IORQ** signals.  

### 4.1.2  
**Second Memory Cell**  

The memory cell for detecting the second part of the **/M1 cycle** must have a logical **0** at its output exactly at the time of one positive edge of the video clock. This is achieved by connecting the processor's **/MREQ** signal to the **D input** and the **/RFSH** signal to the **reset input** of the memory cell. In this case, the processor and the memory cell share the clock signal.  

From **Figure 25**, it is clear that the correct operation of the circuit depends on the delay between the positive edge of the processor clock and the **/RFSH** signal. Here too, the manufacturer only guarantees a **maximum delay**, while a **minimum delay** is also critical for proper operation.  

imagen

**Figure 25**: *Timing diagram of the second D flip-flop (M1 cycle detection).*

### 4.2  **Microprocessor Bus Wiring**  

The original circuit has a very simple address decoder. In addition to the incomplete decoding of addresses for the latch and keyboard, which has already been mentioned, it also has the characteristic of not considering the **RD** and **WR** signals, which are used to distinguish between the microprocessor's read and write requests to the address space.  

If a program running on the microprocessor attempts to write to a part of the address space occupied by a device that does not support writing (e.g., ROM or keyboard), two devices with low-impedance outputs are connected to the data bus. Due to the technology of the integrated circuits used in the original circuit (NMOS for the microprocessor and EPROM, the rest being low-power Schottky), this flaw did not pose a risk to the circuit's lifespan. The outputs of the integrated circuits in these technologies have a relatively high output impedance (on the order of kiloohms) in the logical **1** state, which limits the short-circuit currents that could flow on the bus in such cases.  

On the other hand, the outputs of modern CMOS circuits have low output impedance in both defined states. Therefore, the Galaksija replica includes isolation resistors (**R10-R17** and **R30**) connected to the data bus, which limit the current on the bus in the mentioned cases.  

imagen

**Figure 26**: *Memory layout of the original Galaksija.*  

### 4.3 Keyboard Connection

The keys of the Galaksija keyboard are arranged in an 8 x 7 matrix so that their addresses in the microprocessor's address space correspond as closely as possible to the arrangement of corresponding characters in the ASCII code table (Figure 7). This way, the operating system code that converts the key scan code to the ASCII code character corresponding to the key can be significantly smaller, as relatively extensive tables are not needed for conversion.

Since the physical arrangement of keys generally does not correspond to the arrangement of characters in the ASCII table, this feature significantly increased the complexity of the keyboard's printed circuit board. In its original version, it was single-sided and therefore required many manually made jumpers.

The EPROM read-only memory is, besides the microprocessor and working memory, the only highly integrated circuit and as such one of the more expensive parts of Galaksija. From this perspective, it becomes understandable that the increased manufacturing complexity was a good compromise for a smaller operating system footprint, which allowed the use of cheaper EPROM circuits with lower capacity. Additionally, the required manual creation of jumpers did not affect the selling price of computer self-assembly kits, which was the only planned sales method when designing the computer.

### 4.4 Use of R Register

Using the microprocessor for screen display to reduce hardware complexity was a relatively common approach in early home computers. Similar approaches are used, for example, by Sinclair ZX80 and ZX81 computers. Galaksija's unique feature is that it uses the dynamic memory refresh function (second half of M1 cycle, R register) for this purpose. Sinclair computers, on the other hand, use the first half of the M1 cycle to transfer data from working memory to the shift register [11].

## **Summary of Peculiarities in the Original Circuit**

| **Design Feature** | **Effect** | **Issue** |
|---|---|---|
| **Flip-Flops for Interrupts** | Saves components by detecting M1 cycles | Timing is unreliable across different Z80 chips |
| **Minimal Address Decoding** | Reduces chip count | Causes address aliasing and unexpected behavior |
| **Non-Standard Keyboard Wiring** | Simple circuit | Causes conflicts with other I/O devices |
| **Use of R Register for Random Numbers** | Eliminates the need for a true RNG | Not portable across all Z80 variants |

### 5 Specifics of the Operating System
[Up](#Replica-of-the-Galaksija-Microcomputer) [Previous]((#4-Specifics-of-the-Oiginal-Galaksija-Circuit)) [Next](#6-conclusion)

As mentioned earlier, reducing the size of the operating system stored in EPROM memory was one of the effective methods of lowering the overall system cost. Because of this, the operating system contains many optimizations that reduce code size, but on the other hand make reverse engineering very difficult and reduce code readability. In particular, the usefulness of automatic disassembler programs is greatly reduced, as some of the described approaches cause the disassembler to lose synchronization with the code executed by the microprocessor. In this case, manual verification of results and disassembly of machine code in parts where the microprocessor entry point is known is required.

The Galaksija operating system (ROM A) can be divided into the following components:
- Hardware initialization routines
- Video driver
- Keyboard driver and basic terminal emulation
- Magnetic tape signal modulation and demodulation code
- Floating-point arithmetic routines
- BASIC interpreter

The working memory organization is shown in Figure 26.

imagen

**Figure 26**: Working Memory Organization (darkened fields are occupied by system variables)

Literature suggests that the operating system is based on Microsoft Level 1 BASIC [12]. This is likely an error. Comparison with the only 4 KB BASIC interpreter from Microsoft (BASIC for the Altair microcomputer) shows that the program codes are very different: Altair BASIC uses only Intel 8080 microprocessor instructions, while essential parts of Galaksija's operating system also use instructions specific to the Zilog Z80 microprocessor. Additionally, Altair BASIC's code [13] takes advantage of the fact that it runs in RAM, making its operation dependent on the ability to modify code during program execution at certain points. The data structures used also differ significantly (for example, floating-point number notation, BASIC program notation, etc.). The only similarity between Galaksija's and Altair's code is restart 0x08 (on Galaksija 0x10), which performs a similar function and is similarly implemented.

It's more likely that Galaksija's operating system is based on the Tandy TRS-80 Model I microcomputer operating system. The first version of the operating system (modified Tiny Basic by Li-Chen Wang) used a 4 KB ROM and has very similar characteristics to Galaksija's operating system: identical error messages ("HOW?", "WHAT?", "SORRY"), similar modulation for storing data on magnetic tape, partially identical machine code for performing floating-point operations, etc. In general, the TRS-80's hardware capabilities are similar to Galaksija (same pseudo-graphic mode, same keyboard connection to the processor bus, etc.).

For the purposes of reverse engineering Galaksija's operating system, a new disassembler program z80dasm was created, which is included in the appendix. The contents of ROM A in the form of assembly source code, created with z80dasm, is included in the appendix.

Below are descriptions of some of the optimization approaches used with examples from ROM A's contents.

### 5.1 Program Code Polymorphism

Some parts of the machine code stored in EPROM memory are interpreted differently by the microprocessor on different occasions.

Certain sequences of machine instructions, for example, are interpreted differently depending on the jump address. Table 6 shows an example of such code that is interpreted in three different ways in three different cases. When jumping to address 0x0390, the value 0x0f0e is written to register HL, when jumping to address 0x0393, the value 0x0f9b, and when jumping to 0x0396, the value 0x0fee.

Similarly, code is shortened in several places in the operating system code. In most cases, this involves replacing a jump over an unwanted instruction with a load instruction to an unused register. This way, one byte of program code is saved for each execution branch compared to using the processor's jr instruction.

In certain cases, the Z80 microprocessor's machine code is also interpreted as a data structure.

The first such example can be found at address 0x0098 (Table 7), where the code is also interpreted as an ASCII string. Characters from the upper half of the ASCII code table are interpreted exclusively as 8-bit load (ld) instructions with register operands [14], which simplifies the selection of a text string that matches the microprocessor code.

| Address | Hex | Processor Interpretation || |
|---|---|---|---|---|
| 0x0390  | 0x2e | 1 →ld l,0ehh | | | 
| 0x0391  | 0x0e | | | | 
| 0x0392  | 0x01 | ld bc,9b2eh  | | | 
| 0x0393  | 0x2e | | 2 →ld l,9bh | |
| 0x0394  | 0x9b | | | |
| 0x0395  | 0x01 | | ld bc,ee2eh | |
| 0x0396  | 0x2e | | | 3 →ld l,eeh  |
| 0x0397  | 0xee | | | |
| 0x0398  | 0x26 | ld h,0fh | ld h,0fh | ld h,0fh |
| 0x0399  | 0x0f | | | |

**Table 6:** Example of machine code polymorphism in the Galaxy operating system. The HL register is set to different values depending on the entry point (→) of the microprocessor

| **Adr.** | **Hex** | **ASCII** | **Processor Interpretation of Instructions** |
|---|---|---|---|
| 0x0098 | 0x42 | B | ld b,d |
| 0x0099 | 0x52 | R | ld d,d |
| 0x009A | 0x45 | E | ld b,l |
| 0x009B | 0x41 | A | ld b,c |
| 0x009C | 0x4B | K | ld c,e |
| 0x009D | 0x00 | NUL | nop |

**Table 7:** Example of using machine code as the ASCII string "BREAK".

| **Adr.** | **Hex** | **Data** | **Processor Interpretation of Instructions** |
|---|---|---|---|
| 0x00A0 | 0x00 | M=0x800000, S=+1, E=0x01 | nop |
| 0x00A1 | 0x00 | M=0x800000, S=+1, E=0x01 | nop |
| 0x00A2 | 0x80 | M=0x800000, S=+1, E=0x01 | add a,b |
| 0x00A3 | 0x00 | M=0x800000, S=+1, E=0x01 | nop |

**Table 8:** Example of using machine code as a 4-byte floating-point constant (Appendix, page 67).

The second example is located at address **0x00A0** (Table 8). Here, the machine code is also interpreted as a floating-point number: **+1 · 0x800000 · 2^(0x01−24) = 1.0**.  

### 5.2  
**Multifunctionality of Data Structures**  

The EPROM memory contains a series of constant data structures, mostly interspersed with machine code. Some of these structures are interpreted by the operating system in multiple ways.  

One such example is the table of ASCII codes for the keyboard, located at addresses **0x0D70** to **0x0D99** (Table 9).  

- **KEY SHIFT SYM TABLE** at address **0x0D70** is used to convert key codes into ASCII character codes. It stores ASCII codes in an order corresponding to the addresses of keys in the microprocessor's address space (Figure 7). For example, the first row in the table corresponds to the key at address **0x1F**. The first column contains ASCII codes for characters when the key is pressed with the **SHIFT** key, while the second column contains ASCII codes for characters when the key is pressed without **SHIFT**.  
- **KEY SHIFT YU TABLE** at address **0x0D94** is used for entering Yugoslav characters. It contains ASCII characters corresponding to keys that, when pressed with **SHIFT**, input diacritical marks.  

The **KEY SHIFT YU TABLE** occupies positions in the larger **KEY SHIFT SYM TABLE** that correspond to the keys at addresses **0x31** and **0x32**. These addresses belong to the **BREAK** and **REPEAT** keys, which the operating system handles separately. As a result, the ASCII codes assigned to these keys in the **KEY SHIFT YU TABLE** are irrelevant.  

Here is the information rearranged into a table with four columns: **Adr.**, **Hex**, **SYM TABLE**, and **YU TABLE**:

| Address | Hex  | Symbol | SYM_TABLE  | YU TABLE |
|---|---|---|-----|---|
| 0x0d70  | 0x20 | 0x1f | ␣ ␣ | |
| 0x0d71  | 0x20 | | | |
| 0x0d72  | 0x5f | 0x20 | _ 0 | |
| 0x0d73  | 0x30 | | | |
| 0x0d74  | 0x21 | 0x21 | ! 1 | |
| 0x0d75  | 0x31 | | | |
| 0x0d76  | 0x22 | 0x22 | " 2 | |
| 0x0d77  | 0x32 | | | |
| 0x0d78  | 0x23 | 0x23 | # 3 | |
| 0x0d79  | 0x33 | | | |
| 0x0d7a  | 0x24 | 0x24 | $ 4 | |
| 0x0d7b  | 0x34 | | | |
| 0x0d7c  | 0x25 | 0x25 | % 5 | |
| 0x0d7d  | 0x35 | | | |
| 0x0d7e  | 0x26 | 0x26 | & 6 | |
| 0x0d7f  | 0x36 | | | |
| 0x0d80  | 0xbf | 0x27 | □ 7 | |
| 0x0d81  | 0x37 | | | |
| 0x0d82  | 0x28 | 0x28 | ( 8 | |
| 0x0d83  | 0x38 | | | |
| 0x0d84  | 0x29 | 0x29 | ) 9 | |
| 0x0d85  | 0x39 | | | |
| 0x0d86  | 0x2b | 0x2a | + ; | |
| 0x0d87  | 0x3b | | | |
| 0x0d88  | 0x2a | 0x2b | * : | |
| 0x0d89  | 0x3a | | | |
| 0x0d8a  | 0x3c | 0x2c | < , | |
| 0x0d8b  | 0x2c | | | |
| 0x0d8c  | 0x2d | 0x2d | - = | |
| 0x0d8d  | 0x3d | | | |
| 0x0d8e  | 0x3e | 0x2e | > . | |
| 0x0d8f  | 0x2e | | | |
| 0x0d90  | 0x3f | 0x2f | ? / | |
| 0x0d91  | 0x2f | | | |
| 0x0d92  | 0x0d | 0x30 | CR CR | |
| 0x0d93  | 0x0d | | | |
| 0x0d94  | 0x58 | 0x31 | X C | Ĉ shift X |
| 0x0d95  | 0x43 | | | Ċ shift C |
| 0x0d96  | 0x5a | 0x32 | Z S | Ź shift Z |
| 0x0d97  | 0x53 | | | Ṡ shift S |
| 0x0d98  | 0x0c | 0x33 | FF NUL | |
| 0x0d99  | 0x00 | | | |

**Table 9:** Example of multifunctionality of data structures. A portion of memory is interpreted as the content of two different tables.

## 5.3  **Organization of Program Code**  

The operating system, due to optimization, is not strictly divided into closed units—program functions. Instead of standard function calls using **call** and **ret** instructions, a combination of **call** instructions and jumps (**jp** or **jr**) is used. This approach saved a large number of **ret** instructions that would otherwise be needed to end functions, and it also improved the operating system's speed (as fewer stack operations are required).  

Figure 27 shows a typical arrangement of functions:  
- **Multiple Entry Points:** A function often has multiple entry points. Depending on the entry point, the function's behavior changes slightly. For example, the first entry point performs an operation on the string at address **DE+1**, while the second entry point performs the same operation at address **DE+0** (see **f1a**, **f1b**, and **f1c** in Figure 27).  
- **Function Chaining:** Function **f2** calls function **f1a** just before its end. Instead of using a **call f1a** instruction, function **f2** is placed in ROM memory immediately before function **f1**. This allows the microprocessor to continue execution into the next function without a jump. The final **ret** instruction then returns execution to the code that called function **f2**. This saves an entire **call** instruction (3 bytes in the best case) and is sometimes used even when the called function is not the most suitable.  
- **Shared Code:** Functions often share the same ending code (just before the **ret** instruction). Instead of repeating this code in every function, it is written only once (see **fend** in Figure 27). Other functions are either placed in ROM memory so that the microprocessor reaches this code without a jump (**f1** and **f2**) or jump to it using **jp** or **jr** instructions (**f3**).  

Side effects of functions are also frequently used in the code. For example, the **CLEAR LINE** function, whose main task is to clear one screen line, is also used in some cases to move the pointer in the **HL** register.  

Note: For example, the **SAVE WORD** function is called to store a checksum at the end of the **SAVE** routine, even though calling **SAVE BYTE** would have been more appropriate, as it would not save an unnecessary byte to the tape.  

### 5.4  **Use of Processor Registers**  

The relatively unstructured nature of the code results in consistent use of registers. The patterns in Table 10 are followed by the vast majority of the operating system's code.  

imagen

Figure 27

| **Register** | **Description** |
|---|---|
| DE | Pointer to the current character in the BASIC interpreter |
| HL | Pointer to a BASIC variable |
| IX | Pointer to the top of the arithmetic stack |
| IY | Pointer to the function executed during a video interrupt |
| HL’, C’, HL  | First operand for floating-point operations |
| DE’, B’, DE  | Second operand for floating-point operations |

**Table 10:** Typical use of processor registers in the operating system.

imagen

Figure 28

## **5.4 Register-Based Processing**

To maximize **execution speed**, the OS minimizes **memory accesses** by:

- Using **Z80 registers** whenever possible.
- Keeping **critical variables in registers** instead of RAM.
- Using **alternate register sets** for multitasking-like behavior.

**Table 7**: *Typical register usage in the Galaksija OS.*

| **Register** | **Purpose** |
|---|---|
| **AF** | Video sync counter |
| **BC** | Character printing loop |
| **DE** | Memory address pointer |
| **HL** | Current cursor position |
| **IX/IY** | Interrupt service routines |

This approach reduces **bus contention**, improving **execution speed**, but also makes **interrupt handling more complex**.

## **5.5 Processor Stack**  

The operating system's code often directly modifies values on the processor stack, which is uncommon elsewhere. One example of stack manipulation is shown in Figure 28. Here, the function at address **0x0393** calls the function at **0x0C8F** by pushing its address onto the stack, while the next function (**0x2BA9**) is called using the **jp** instruction instead of **ret**. This way, the **ret** instruction in the function at **0x2BA9** jumps to the called function at **0x0C8F**, rather than returning execution to **0x0393**.  

The stack is also used to pass pointers to arguments for certain functions. An example is shown in Figure 29. Here, the **READ PAR** function uses the address saved at the top of the stack by the **rst** instruction as the address of two operands (at addresses **0x0134** and **0x0135**).  

At the end of execution, the function adds **2** to the pointer it initially read from the top of the stack and returns it to the top of the stack. This way, the **ret** instruction at the end returns processor execution to address **0x0136**.  

A similar implementation is used for the **BASIC ERROR** function, where the value at the top of the stack points to an error message.  

This approach saves additional machine code that would otherwise be needed to load function arguments into registers or to load a pointer to a data structure. This simplification, in the case of a large number of calls to a specific function, more than compensates for the additional code required in the function itself.  

Such interweaving of machine code and function arguments is one of the main reasons for the aforementioned difficulties with automatic disassembler programs. Unusual uses of the processor stack also greatly complicate the use of software simulators for exploring operating system functions, as they obscure the function call trace (backtrace).  

```asm
rst 18h          ;0133  Call the READ_PAR function
db '('           ;0134 Define byte: ASCII '('
db l015dh-$-1    ;0135 Define byte: Calculate offset to label l015dh

rst 08           ;0136 Call routine at address 08h
inc hl           ;0137 Increment HL register
add hl, hl       ;0138 Add HL to itself (HL = HL * 2)
```

**Figure 29:** Example of using the stack to pass a pointer to function arguments.  

## **5.6 Cassette Tape Data Storage**

Simple pulse modulation is used for storing data on tape. The timing diagram of the signal is shown in Figure 30, the timing intervals are detailed in Table 11, and the logical meaning of individual stored bytes is provided in Table 12.  

The typical data transfer rate achieved is approximately **330 bits/s**. The choice of simple modulation and low transfer speed is most likely due to the limited space for modulation and demodulation routines in the EPROM memory. Microcomputers with similar hardware but larger ROM capacities achieve significantly higher transfer speeds (for example, the Sinclair Spectrum typically achieves **1500 bits/s**).  

imagen

**Figure 30:** *Timing diagram of the modulation used for storing data on magnetic tape.*

### Table 11: Values of symbols (for Figure 30)

| Symbol  | Comment | Min | Typical | Max | Unit |
|---|---|-----|---|-----|---|
| tpos | Duration of positive pulse | 140 | 650 | - | T us |
| | | 45 | 210 | - | T us |
| tneg | Duration of negative pulse | 650 | - | T us |
| | | 210 | - | T us |
| tbase | Duration of recording one bit | 7800 | 9200 | 16000 | T ms |
| | | 2.5 | 3.0 | 5.2 | ms |
| tone | Delay between 1st and 2nd pulse | 4400 | 4600 | 7400 | T ms |
| | | 1.4 | 1.5 | 2.4 | ms |
| tbyte | Duration of recording one byte | - | 74000 | - | T ms |
| | | - | 24.0 | - | ms |
| tinterbyte | Delay between 2 bytes | 8200 | 13000 | - | T ms |
| | | 2.7 | 4.3 | - | ms |

### Table 12: Meaning of individual bytes in the data record for storage on tape recorder

| Offset | Length | Comment |
|---|---|---|
| 0x00 | 0x01 | Start byte (0xa5) (1010 0101) |
| 0x01 | 0x02 | Address of the first data byte (lowest address byte first) |
| 0x03 | 0x02 | Address of the last data byte + 1 (lowest address byte first) |
| 0x05 | N | Data bytes |
| 0x05+N | 0x01 | Checksum (the number that needs to be added to the sum of previous bytes modulo 256 to get 0xff) |

### Table 13: Data part of the record when storing a BASIC program on tape recorder

| Address | Length | Content | Comment |
|---|---|---|---|
| 0x2c36  | 0x02 | 0x2c3a  | Address of the first byte of the BASIC program (lowest address byte first) |
| 0x2c38  | 0x02 | 0x2c3a+N | Address of the last byte of the BASIC program + 1 (lowest address byte first) |
| 0x2c3a  | N | - | BASIC program |

The operating system does not distinguish between storing data, machine code, and BASIC programs. The data structure in Table 12 only allows storing the contents of any part of the microprocessor's address space.

In the case of storing a BASIC program, the operating system stores data from address 0x2c36 to the end of the BASIC program on the tape recorder. When later loading the stored data, the system variables BASIC START and BASIC END at addresses 0x2c36 and 0x2c38 are overwritten, which allows the operating system to locate the loaded program.

## Notes:

### Working with a tape recorder

Galaksija is connected to the tape recorder with a transmission speed of 280 baud (280 bits are written to the tape every second). This speed guarantees reliability even though it is lower than that offered by some commercial models.

As an illustration of the reliability/speed problem, let a quote from the instruction manual of the BBC computer, which is advertised as one of the most complete and powerful desktop computers on the market: "the recording speed is 1300 baud, but we suggest that, when recording an important program, you enter the next command and thus reduce the speed to 300 baud...".

The basic memory of the Galaksija computer is not large, so recording on a cassette does not take too long, and the verification of the recording eliminates all other potential problems.

**Table 9**: *Comparison of original and replica Galaksija hardware.*

| **Feature** | **Original Galaksija** | **New Galaksija Replica** |
|---|---|---|
| **Processor** | Zilog Z80A (NMOS) | Zilog Z84C0008 (CMOS) |
| **ROM Size** | 4 KB | 32 KB |
| **RAM Size** | 2, 4, or 6 KB | 8 KB |
| **Video Output** | Composite Video | Composite Video (Optimized for modern displays) |
| **Cassette Interface** | Analog | Improved ADC/DAC circuit |

### **6 Conclusion**  
[Up](#Replica-of-the-Galaksija-Microcomputer) [Previous]((#5-Specifics-of-the-Operating-System)) [Next](#bibliography)

The creation of the Galaksija replica demonstrated that replicating even a small electronic system like the Galaksija is not a simple task. It requires knowledge of both analog and digital electronics, as well as assembly programming. On the other hand, this work proves that creating a functional replica is possible based solely on preserved documentation and software, even when a working original is unavailable for analysis.  

Before designing and building the replica, several side issues had to be addressed: reverse-engineering the original electronic circuit was, of course, planned, but the inadequacy of current tools for analyzing Z80 machine code was not anticipated. This required a detour from the main path and the creation of a usable Z80 disassembler. Due to difficulties in understanding the operating system's behavior, it was necessary to study the system while running test programs, rather than relying solely on static analysis of the ROM contents. Developing these test programs, in turn, required the creation of development tools first.  

The construction of the replica's keyboard also posed challenges. Due to the overwhelming prevalence of standard PC keyboards within the available resources, it was not possible to create a suitable replacement for the original Galaksija keyboard. As a result, the modern replica has a lower-quality, foil-covered keyboard (whereas the professional keyboard was one of the few technical advantages the Galaksija had over its competitors).  

These detours contributed to the results covering a slightly broader area than originally planned in the project's objectives. This also led to a somewhat more extensive list of appendices.  

Today, the importance of writing clear and simple programs is emphasized over highly optimized but difficult-to-understand code. The results of this work confirm this, as the excessively optimized machine code proved very difficult to understand. At the same time, the associated preserved documentation turned out to be practically useless. An unexpected consequence of this optimization was the reduced usability of modern disassembler tools, requiring manual translation of machine code into assembly based on instruction tables.  

Despite better documentation, the findings regarding hardware were similar to those for software: it became clear that designing simple and understandable circuits is just as important as documentation. Excessive optimization in terms of the number of electronic components, such as the Galaksija's use of sequential circuits instead of combinational ones, significantly increased the complexity of the work. On several occasions, preserved documentation, due to printing errors, made the work more difficult rather than easier, often requiring cross-referencing data from different sources (e.g., wiring diagrams and PCB layouts).  

On the other hand, the results highlight the positive impact of exclusively using standard electronic components (especially integrated circuits). Creating a similar replica of a microcomputer that relies on an application-specific integrated circuit (ASIC) would be a significantly more challenging task.  

The importance of publicly releasing documentation was also evident in this project. Many microcomputers from this era were lost primarily because their documentation disappeared along with the companies that carefully guarded it. Similarly, the absence of copy protection in software had a positive impact on its preservation, as such protections often led to the loss of a significant portion of software for similar microcomputers.  

### **Bibliography**
[Up](#Replica-of-the-Galaksija-Microcomputer) [Previous](#conclusion) [Next](#appendix)

[^1] Hišni računalnik. Ljubljana, Mladinska knjiga, 1984, str. 42-46.

[^2] Antonić, V.: Napravi i ti računar Galaksija. Računari u vašoj kuči,januar 1984, str. 50-56.

[^3] ZX81 Assembly Instructions. Sinclair Research Ltd, 1981.

[^4] Servicing Manual for ZX Spectrum. Thorn Datatech Ltd, Sinclair Research Ltd, 1984.

[^5] Commodore 64 Service Manual. Commodore Business Machines Inc,1985.

[^6] Z80 Family CPU User Manual. San Jose, ZiLOG Inc., 2005.

[^7] Benson, K. B.: Television Engineering Handbook. McGraw-Hill Inc., 1985.

[^8] Wedam, A.: Radiotehnika: ojačevalniki in sprejemniki. Ljubljana,Državna založba Slovenije, 1955.

[^9] Bandwidth Versus Video Resolution. Maxim Integrated Products, Dallas Semiconductor,2005. http://www.maxim-ic.com/appnotes.cfm/appnote number/750

[^10] Z8400/Z84C00 NMOS/CMOS Z80 CPU Central Processing Unit: Product specification. ZiLOG Inc.

[^11] Rigter, W.: ZX81 Video Display System. 1996. http://home.germany.net/nils.eilers/zx81/wilfvid.htm

[^12] Ristanović, D.: Računar Galaksija. http://user.sezampro.yu/ dejanr/galaks.htm

[^13] Harris, R.: Altair BASIC 3.2 (4K) - Annotated Disassembly. http://www.interact-sw.co.uk/altair/index2.html

[^14] Dinu, C.: Decoding Z80 opcodes. http://z80.info/decoding.htm

[^15] Ristanović, D.: Računar Galaksija Uputstvo za upotrebu.

[^16] Ristanović, D.: Galaksija bez tajni. Računari, July 1984, pages 53-63.

## **Appendix**
[Up](#Replica-of-the-Galaksija-Microcomputer) [Previous](#bibliography) [Next](#declaration)

### A **Voltage Inverter**  

The voltage inverter must produce a stabilized supply voltage of **−5V** under all operating conditions of the video amplifier.  

SPICE simulations of the video amplifier in both extreme cases (a completely white screen and a completely black screen) showed that the video amplifier requires a current of **25 to 34 mA** for operation.  

Due to its simple circuit and reliable operation, a **switched capacitor** implementation with a linear voltage regulator was chosen. The low output current minimizes the drawbacks of this approach (such as high losses compared to an inductor-based design).  

The switching part (integrated circuit **U11**, capacitor **C4**, and diodes **D2** and **D3**) operates at a frequency of approximately **10 kHz** and produces an unstabilized voltage of approximately **−9V**. This voltage is then stabilized by the regulator in the integrated circuit **U22**.  

The results of measurements of the output voltage as a function of the output current are shown in **Figure 31**.  

imagen

imagen

**Figure 31:** Results of voltage measurements before (**Usw**) and after (**Uout**) the voltage regulator, as a function of the output current **Iout**.  

### B Calculation of the Pulse Amplifier  

Assume that the input pulse is rectangular in shape and that the connected tape recorder has a low output impedance.  

First, calculate the **maximum collector current**, while also assuming the **minimum current through R1** at which the amplifier output is at a logical **0**.  

The minimum collector current (**ICmin**) is calculated as:  
$$IC_{\text{min}} = \frac{U_{CC} - U_{CE_{\text{sat}}}}{R1}$$  
*(Equation 1)*  

Where:  
- $$ U_{CC} $$ = Supply voltage  
- $$ U_{CE_{\text{sat}}} $$ = Collector-emitter saturation voltage  
- $$ R1 $$ = Resistor value  

The minimum base current (**IBmin**) required to achieve **ICmin** is:  

$$IB_{\text{min}} = \frac{IC_{\text{min}}}{\beta}$$  
*(Equation 2)*  

Where:  
- $$\beta$$ = Current gain of the transistor  

If the above assumptions hold, the capacitor **C15** initially charges primarily through the base of transistor **Q7** after the first edge of the pulse. Once the voltage at the base drops to the base-emitter voltage (**UBE**) of transistor **Q7**, the capacitor continues to charge mainly through resistor **R33**.  

The output pulse of the amplifier lasts as long as the base current exceeds **IBmin**.  

imagen

Due to the exponential **IB (UBE)** characteristic of the transistor, the capacitor charges through the base in a very short time. The width of the output pulse is primarily determined by the charging through resistor **R33** and the resulting **RC time constant** of the **R33 C15** circuit.  

Assume that the base current becomes negligible when it drops to approximately one-tenth of the current through the resistor. At this point, the base voltage is:  

imagen

$$U_{BE_{\text{start}}} = U_T \ln\left(\frac{U_{BE} \beta}{I_S R33 \cdot 10} + 1\right)$$
*(Equation 4)*  

Where:  
- $$\( U_T \)$$ = Thermal voltage  
- $$\( I_S \)$$ = Saturation current of the transistor  
- $$\( \beta \)$$ = Current gain of the transistor  

Similarly, the base voltage when the minimum base current (**IBmin**) flows is:  

$$U_{BE_{\text{stop}}} = U_T \ln\left(\frac{I_{B_{\text{min}}} \beta}{I_S} + 1\right)$$  
*(Equation 5)*  

The duration of the pulse is then:  

$$t = R33 \cdot C15 \cdot \ln\left(\frac{U_{BE_{\text{start}}}}{U_{BE_{\text{stop}}}}\right)$$  
*(Equation 6)*  

The required capacitance **C15** for a known resistor value and pulse duration is:  

$$C15 = \frac{t}{R33 \cdot \ln\left(\frac{U_{BE_{\text{start}}}}{U_{BE_{\text{stop}}}}\right)}$$  
*(Equation 7)*  

For a resistor **R33 = 1 kΩ** and a pulse duration **t = 100 µs**, we obtain a value of **C15 ≈ 0.72 µF**, which is approximately **1 µF**. The minimum pulse duration of **45 µs** is derived from the **LOAD READ PULSE** loop at addresses **0x0EF9** to **0x0F05**. For greater reliability, a value approximately twice as large was used.  

### C Floating-Point Numbers  

Galaksija's operating system uses a stack-based calculator with **RPN (Reverse Polish Notation)** for evaluating mathematical expressions internally. For example, all BASIC expressions are internally converted into this form before calculation, and the complexity of expressions is limited only by the memory available for the arithmetic stack.  

The system uses **two different formats** for floating-point numbers:  
1. **4-byte format:** Used for long-term storage of values (e.g., for BASIC variables and arrays).  
2. **5-byte format:** Used for storing intermediate calculation results (e.g., values on the arithmetic stack). This format is more suitable for arithmetic operations due to its data layout.  

This approach achieves a compromise between the speed of arithmetic operations and memory requirements.  

Both formats always contain **normalized values** and use:  
- **24 bits** for the mantissa,  
- **8 bits** for the exponent, and  
- **1 bit** for the sign.  

The value of the number is determined by the following equation:  

$$N = 
\begin{cases} 
+1 \cdot M \cdot 2^{E-24} & \text{if } S = 0 \\
0 & \text{if } E = -128 \\
-1 \cdot M \cdot 2^{E-24} & \text{if } S \neq 0 
\end{cases}$$
*(Equation 8)*  

Where:  
- \( M \) = Unsigned mantissa value,  
- \( E \) = Signed exponent value,  
- \( S \) = Sign bit value, and  
- \( N \) = Represented number.  

This format allows numbers to be represented in the following range:  

$$N \in \left[ -1 \cdot (2^{24} - 1) \cdot 2^{127}, +1 \cdot (2^{24} - 1) \cdot 2^{127} \right]$$  
*(Equation 9)*  

The format does not support non-numeric values (e.g., infinity, undefined values, etc.).  

The interpretation of individual bits in both formats is shown in **Tables 14** and **15**. In the 4-byte format, the **most significant bit of the mantissa (M23)** is omitted because it is always **1** due to the mandatory normalization of numbers.  

| **Address** | **Bit** | **7** | **6** | **5** | **4** | **3** | **2** | **1** | **0** | |
|---|---|---|---|---|---|---|---|---|---|---|
| IX - 5 | L’ E’ | M7 | M6 | M5 | M4 | M3 | M2 | M1 | M0 | mantisa |
| IX - 4 | H’ D’ | M15 | M14 | M13 | M12 | M11 | M10 | M9 | M8 | |
| IX - 3 | C’ B’ | M23 | M22 | M21 | M20 | M19 | M18 | M17 | M16 | |
| IX - 2 | L E | E7 | E6 | E5 | E4 | E3 | E2 | E1 | E0 | exponent|
| IX - 1 | H D | S | S6 | S5 | S4 | S3 | S2 | S1 | S0 | sign |

**Table 14:** 5-byte floating-point number format.

| **Bit** | **7** | **6** | **5** | **4** | **3** | **2** | **1** | **0** |
|---|---|---|---|---|---|---|---|---|
| HL + 0  | M7 | M6 | M5 | M4 | M3 | M2 | M1 | M0 |
| HL + 1  | M15 | M14 | M13 | M12 | M11 | M10 | M9 | M8 |
| HL + 2  | E0 | M22 | M21 | M20 | M19 | M18 | M17 | M16 |
| HL + 3  | S7 | E7 | E6 | E5 | E4 | E3 | E2 | E1 |

**Table 15:** 4-byte floating-point number format.

### **Declaration**  
[Up](#Replica-of-the-Galaksija-Microcomputer) [Previous](#appendix) 

I declare that I have prepared this thesis independently under the guidance of my mentor, Prof. Dr. Tadej Tuma, Univ. Dipl. Ing. El. Any assistance provided by other collaborators has been fully acknowledged in the acknowledgments section.

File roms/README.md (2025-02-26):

# ROM listings
There a 4 for ROMS, from A to D or 1 to 4.

Here I provide asm files for roms A, B, and C. For D only some info from a magazine is included.

I have used the rom files available at https://github.com/mejs/galaksija/blob/master/roms/ and they are located in the folder original.

Using make_roms.sh (https://github.com/issalig/galaksija/tree/main/roms/make_roms.sh) will assemble roms A, B and C.

**local** directory (https://github.com/issalig/galaksija/tree/main/roms/local) is used to assemble the .asm files

## ROM A
ROM A listing has been downloaded from https://github.com/mejs/galaksija/tree/master/roms and comes from avian site https://web.archive.org/web/20221228104534/https://www.tablix.org/~avian/galaksija/rom/rom1.html 

Assembled ROM A is the same as  https://github.com/mejs/galaksija/blob/master/roms/ROM%20A/ROM_A_without_ROM_B_init_ver_28.bin

ROM A may be patched for ROM B autostart by doing two changes. One is cosmetic and increases version number to 29. The second change initializes ROM B at start-up to make its commands accessible. If there is no initialization patch, ROM B has to be initialized at startup by typing A=USR(&1000)  

Differences between ROM_A_without_ROM_B_init_ver_28.bin and ROM_A_with_ROM_B_init_ver_29.bin are:

```bash
z80dasm original/ROM_A_without_ROM_B_init_ver_28.bin  -l -g 0x0000 -a -t > 28
z80dasm original/ROM_A_with_ROM_B_init_ver_29.bin  -l -g 0x0000 -a -t > 29
diff 28 29
```

```
46c46
< 	inc e			;0037	1c
---
> 	dec e			;0037	1d
734,735c734
< 	ld a,00ch		;03f9	3e 0c
< 	rst 20h			;03fb	e7
---
> 	call 01000h		;03f9	cd 00 10
```

To check which version of ROMS do you have you can try from BASIC in your own Galaksija
```basic
DUMP &0037, 1
```
```1C``` corresponds to version 28

```1D``` corresponds to version 29

```basic
DUMP &03F9, 1
```

```3E 0C E7``` is for non ROM B init

```CD 00 10``` is for ROM B init (call 01000h)

The following table shows the BASIC commands and their descriptions for ROM A.

| Command | Description |
|---------|-------------|
| `!...` | Like other BASICs REM - begins comment |
| `#...` | Like other BASICs DATA & Use as prefix before number if it is written in hex |
| `ARR$(x)` | Allocates array of strings. Can only allocate array A$ - with exactly this name |
| `BYTE` | Universal PEEK/POKE tool. PEEK is like `PRINT BYTE(&33F9)`, POKE is like `BYTE &33F9,&C4` |
| `CALL n` | Like other BASICs GOSUB. Allows to use variables for line numbers |
| `CHR$(n)` | ASCII code to character |
| `DOT x, y` | When used as command, draws dot at x,y (X in 0..63, Y in 0..47). Used as function- checks if there is a dot |
| `DOT * ?` | Not specified |
| `EDIT n` | Edit specified BASIC line |
| `ELSE` | For IF |
| `EQ` | Compare strings |
| `FOR` | A typical FOR loop |
| `GOTO` | A standard GOTO |
| `HOME` | Clear screen. Optional argument (HOME x) preserves x characters |
| `IF` | An IF, but there is no THEN! |
| `INPUT` | Make user enter variable |
| `INT(x)` | Return largest integer <=x |
| `KEY(x)` | Is x key pressed? |
| `LIST` | LISTs program. Optional argument specifies from which line |
| `MEM` | How much memory is used? |
| `NEW` | Clears program. Optional argument (NEW x) changes start of BASIC area for potential user data/code |
| `OLD` | Load from tape. Optional argument loads to address (OLD x) |
| `PTR` | Address of variable |
| `PRINT` | Prints expression |
| `RETURN` | Return from GOSUB |
| `RND` | Returns a random float between 0 and 1 |
| `RUN` | Runs a program |
| `SAVE` | Save program to tape. Optional arguments: memory range to be saved (e.g. for data) |
| `STEP` | For FOR |
| `STOP` | Stops running of BASIC program |
| `TAKE` | If the parameter is variable name, reads it. If number - clears data under pointer |
| `UNDOT` | Inverse to DOT |
| `UNDOT * ?` | Not specified |
| `USR` | Calls user routine from memory |
| `WORD` | Double byte PEEK/POKE (see BYTE) |

# ROM B
ROM B listing has been downloaded from https://www.voja.rs/galaksija/ROM%20B%20Listing%20Scans/ROM_B_listing.htm, then it has been converted to text using and LLM. Of course an intense manual work has been necessary to polish ocr results.

I have used this prompt in order to avoid short or uncomplete answers:
```
'I have a listing of z80 assembler. The typical line contains the address, the code of the instruction 
   in hexadecimal, the number of line, a label, a mnemonic of the instruction, the parameters of the 
   instruction and the comments. I want to convert it to text and translate into English the comments that
   are the end of the lines. Also put a ";" before the comment if it does not have it. please provide the 
   full listing and do not miss any column'
```

There are different vesions of ROM B and the difference resides in byte 0x1024 
| ROM name | Byte value |
|----------|------------|
|ROM_B_monitor_value_13.bin | 13 (0xD) |
|ROM_B.bin                  | 12 (0xC) |
|ROM_B_monitor_fix.bin      | 11 (0xB) |

It is possible to generate these different versions by changing MONITOR_FIX value in rom_b.asm. Also you can use sjasmplus -DMONITOR_FIX=13, etc, ...

ROM B includes mathematical functions, machine code utils and some BASIC extensions. The table shows the list of available functions.

| Command | Description |
|---------|-------------|
| `SQR(x)` | Square root |
| `POW(x,y)` | Power, values non-zero |
| `PI` | 3.141... |
| `EXP(x)` | e^x |
| `LN(x)` | Logarithm |
| `SIN/COS/TG` | Trigonometric functions |
| `SIND/COSD/TGD` | Trigonometry for degree measure |
| `ARCTG(x)` | Arctg |
| `ABS(x)` | Absolute value |
| `DEL x, y` | Delete BASIC lines x..y |
| `REN x` | Renumber every X lines (e.g. REN 5 renames 5, 10, 15), but does not touch labels! |
| `"-operator` | A = 10 + "X" - ASCII value of "X". Generally, first character in ""-string |
| `PRINT% "x"` | Value of X in 4-character hex (&0058). PRINT% converts result to 4-digit hex value |
| `DUMP x, y` | Display memory content from X, for Y rows (1 row: 8 bytes) |
| `/word` | Search and show all program lines containing word |
| `INP(x)` | Get content of x port |
| `OUT(x, y)` | Emit byte y to port x. x,y 0..255, port 255 is Centronics expansion |
| `L...` | LPRINT, LLIST, LDUMP - commands to Centronics printer expansion |

Note: ROM B can be started with USR routine `X=USR(&1000)`. In some ROM versions it starts automatically.

# ROM C
ROM C is targeted to Galaksija Plus which is an improved version of Galaksija, with 256x208 monochrome graphics mode, 3-voice sound based on AY-3-8910 and 48 KiB RAM. 
This rom listing has been obtained from https://github.com/mejs/galaksija/blob/master/roms/ROM%20C/ROM%20C%20listing.pdf

It is worth to mention that it differs from https://github.com/mejs/galaksija/blob/master/roms/ROM%20C/ROM_C.bin

However the asm file includes an optional patch to match the original ROM_C.bin

```assembly
        ; BEGIN this part is from the ROM dump but was not in the listing
            IF ROM_C_PATCH        
        CP $FD
        EI
	RST $30
	RST $28
	RST $18
	CP A
	LD A, A
            ENDIF        
        ; END this part is from the ROM dump but was not in the listing
```

# Other links

 - General info https://github.com/mejs/galaksija/blob/master/roms/

 - ROM B info https://www.dejanristanovic.com/refer/galrom2.htm

 - ROM files https://8bitchip.info/galaksija/rom.zip

 - More ROM files https://oldcomputer.info/8bit/galaksija/ROM.7z

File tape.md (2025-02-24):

# Galaksija Computer Tape File Format (GTP)

## Overview

The Galaksija computer tape file format (.GTP) is used for storing programs and data on cassette tapes. The format consists of blocks, each containing metadata and program data.

## File Structure

A typical Galaksija tape file consists of one or more blocks (name, standard or turbo). 

### Name block

| Size (Bytes) | Description |
| --- | --- |
| 1 | `10` |
| 2 | Name length +1 |
| 2 | '00 00' Separator |
| Variable | File Name + `\0` |

### Standard block

| Size (Bytes) | Description |
| --- | --- |
| 1 | `00` |
| 2 | Data Length from (A5 to CRC) |
| 2 | `0000` |
| 1 | `A5` Magic Byte |
| 2 | Start Address (typically 2C36) |
| 2 | End Address + 1 (Start + Data Length)|
| 2 | BASIC (Start + 4)|
| 2 | End Address (Start + Data Length) |
| Variable | Program Data |
| 1 | Checksum (CRC) |

BASIC lines in the program data are coded as 
   - Line number
   - `00`
   - Text of the line
   - `0D`

### Checksum Calculation (CRC)

The CRC is computed as follows:
- It is the sum of all bytes from the **magic byte (`A5`) to the last data byte**, modulo 256.
- The result is then **two's complemented** to obtain the final CRC value.

### Turbo mode

It uses 0x01 as the first byte in the block. For more info look for "TURBO" in roms/rom_c.asm

## Example Breakdown
Tip: You can use GALe emulator (https://galaksija.net/) to write your programs and save them as GTP (without the the header). Just use "SAVE" command from BASIC and press Tape button at the bottom of the screen.

The following bytes correspond to this HELLO WORLD! program.
```basic
10 PRINT "HELLO WORLD!"
```
```
10 06 00 00 00 48 45 4c 4c 4f 00 00 21 00 00 00 a5 36 2c 51 2c 3a 2c 51 2c
0a 00 50 52 49 4e 54 20 22 48 45 4c 4c 4f 20 57 4f 52 4c 44 21 22 0d 53
```
First block contain name (this block is **optional** and this bytes are ignored until a5 in standard block is found.)
- `10` -  Name Block
- `06 00` - Length ( strlen("HELLO\0")=6)
- `00 00` - Separator
- `48 45 4c 4c 4f 00` - String terminated with \0 (HELLO)

Second block is a standard block with a program
- `00` - Standard Block
- `21 00` - Length (33 bytes from a5 to CRC)
- `00 00` - Separator
- `a5` - Magic byte
- `36 2c` - Start data address 0x2c36 for BASIC
- `51 2c` - End data address 0x2c51 (**last byte +1**)
- `3a 2c` - Start of code (0x2c36 + 0x04 (2 words = 4 bytes))
- `51 2c` - End of code 0x2c36 + (0x21 - 0x06)
- `0a 00` - Line number in decimal (0x000a -> 10)
- `50 52 49 4e 54 20 22 48 45 4c 4c 4f 20 57 4f 52 4c 44 21 22 0d` - String (begins ends with CR)
- `P  R  I  N  T     "  H  E  L  L  O     W  O  R  L  D  !  "  \cr`
- `53` - CRC

Load it with OLD and type DUMP &2C36,4. This will dump 4*8 bytes starting at the given address and we can check if everything is correct.
```basic
OLD
DUMP &2C36,4
&2C36:  3A 2C 51 2C 0A 00 50 52
&2C3E:  49 4E 54 20 22 48 45 4C
&2C46:  4C 4F 20 57 4F 52 4C 44
&2C4E:  21 22 00 00 00 00 00 00
```
The previous dump confirms that BASIC start and end pointers are correctly set.

|address | content |
|---|---|
|2C36 | 2C3A |
|2C38 | 2C51 (**last byte +1**) |
|2C3A .. 2C50 | 0A 00 .. 0D |

Some operation tell us 0x2C51 - 0x2C3A =  0x17 -> 23 which is the program length
```asm
0A 00 50 52 49 4E 54 20 22 48 45 4C 4C 4F 20 57 4F 52 4C 44 21 22 00
```
I compiled this information from several sources:
 - https://github.com/z88dk/z88dk/blob/master/src/appmake/galaksija.c
 - https://github.com/mamedev/mame/blob/master/src/lib/formats/gtp_cas.cpp
 - https://oldcomputer.info/8bit/galaksija/buildlog.htm
 - https://fahrplan.events.ccc.de/congress/2012/Fahrplan/attachments/2250_prezentacija.pdf
 - gtpwav

OLD (Output LoaD?) is the command for loading data. Thus, looking at the roms, "OLD" function code is found in ROM A https://github.com/issalig/galaksija/blob/ea546a2fea61937e64ce2bfd1ef2ee66332b27ea/roms/rom_a.asm#L5473 and it reads the data from the cassette that is mapped/wire to address 0x2000 https://github.com/issalig/galaksija/blob/ea546a2fea61937e64ce2bfd1ef2ee66332b27ea/roms/rom_a.asm#L5611
```asm
;; LOAD_WAIT_PULSE
l0ee2h:
	add a,b		;0ee2	4	Add B' to A
	ld hl,02000h	;0ee3	10	Load cassette port address into HL'
 ```

## Tape Data Storage
This text is a translation of Tomaž Šolc thesis (page 55) and explains how data is recorded on the cassete.

Simple pulse modulation is used for storing data on the tape. The time diagram of the signal is shown in Figure 30, the information on the time intervals in Table 11, and the logical meaning of the individual stored bytes in Table 12.

A data transfer rate of approximately 330 bit/s is typically achieved. The choice of a simple modulation and low transfer rate is most likely due to the limited space for modulation and demodulation routines in the EPROM memory, as microcomputers with the same hardware and larger ROM memory achieve significantly higher transfer rates (for example, Sinclair Spectrum typically 1500 bit/s). It is also worth to note that the decoding of data (SAVE and OLD) takes around 200 bytes!!!

https://github.com/issalig/galaksija/blob/3d6b7d963c28612a3463466e2bb71c78f4847ecf/roms/rom_a.asm#L5312
https://github.com/issalig/galaksija/blob/3d6b7d963c28612a3463466e2bb71c78f4847ecf/roms/rom_a.asm#L5479

"0" is coded as a pulse and "1" is coded as two pulses.

imagen

**Figure 30**: Timing diagram of the modulation used for storing data on magnetic tape

### Table 11: Values of symbols (for Figure 30)

| Symbol  | Comment | Min | Typical | Max | Unit |
|---|---|-----|---|-----|---|
| tpos | Duration of positive pulse | 140 | 650 | - | T us |
| | | 45 | 210 | - | T us |
| tneg | Duration of negative pulse | 650 | - | T us |
| | | 210 | - | T us |
| tbase | Duration of recording one bit | 7800 | 9200 | 16000 | T ms |
| | | 2.5 | 3.0 | 5.2 | ms |
| tone | Delay between 1st and 2nd pulse | 4400 | 4600 | 7400 | T ms |
| | | 1.4 | 1.5 | 2.4 | ms |
| tbyte | Duration of recording one byte | - | 74000 | - | T ms |
| | | - | 24.0 | - | ms |
| tinterbyte | Delay between 2 bytes | 8200 | 13000 | - | T ms |
| | | 2.7 | 4.3 | - | ms |

### Table 12: Meaning of individual bytes in the data record for storage on tape recorder

| Offset | Length | Comment |
|---|---|---|
| 0x00 | 0x01 | Start byte (0xa5) (1010 0101) |
| 0x01 | 0x02 | Address of the first data byte (lowest address byte first) |
| 0x03 | 0x02 | Address of the last data byte + 1 (lowest address byte first) |
| 0x05 | N | Data bytes |
| 0x05+N | 0x01 | Checksum (the number that needs to be added to the sum of previous bytes modulo 256 to get 0xff) |

### Table 13: Data part of the record when storing a BASIC program on tape recorder

| Address | Length | Content | Comment |
|---|---|---|---|
| 0x2c36  | 0x02 | 0x2c3a  | Address of the first byte of the BASIC program (lowest address byte first) |
| 0x2c38  | 0x02 | 0x2c3a+N | Address of the last byte of the BASIC program + 1 (lowest address byte first) |
| 0x2c3a  | N | - | BASIC program |

The operating system does not distinguish between storing data, machine code, and BASIC programs. The data structure in Table 12 only allows storing the contents of any part of the microprocessor's address space.

In the case of storing a BASIC program, the operating system stores data from address 0x2c36 to the end of the BASIC program on the tape recorder. When later loading the stored data, the system variables BASIC START and BASIC END at addresses 0x2c36 and 0x2c38 are overwritten, which allows the operating system to locate the loaded program.

## Notes:

### Working with a tape recorder

Galaksija is connected to the tape recorder with a transmission speed of 280 baud (280 bits are written to the tape every second). This speed guarantees reliability even though it is lower than that offered by some commercial models.

As an illustration of the reliability/speed problem, let a quote from the instruction manual of the BBC computer, which is advertised as one of the most complete and powerful desktop computers on the market: "the recording speed is 1300 baud, but we suggest that, when recording an important program, you enter the next command and thus reduce the speed to 300 baud...".

The basic memory of the Galaksija computer is not large, so recording on a cassette does not take too long, and the verification of the recording eliminates all other potential problems.

---
# ******************************
# YOU ARE ENTERING A WIP AREA!!!
# ******************************

TO-DO: Load from TZX (rcmolina maxduino, etc, ...
https://galaksija.net/
https://github.com/rcmolina/Elektronika-Galaksija

https://web.archive.org/web/20221228104534/https://www.tablix.org/~avian/galaksija/rom/rom1.html

---
### System Addresses of ROM 2

The following table presents a map of system variables for the "Galaksija" operating system, BASIC interpreter, and ROM 2. 

(see https://dejanristanovic.com/refer/galrom2.htm)

| Address | Bytes | Initially | Contents |
|---|---|---|---|
| 2800 | 512  | 20 | Video memory |
| 2A00 | 104  | 00 | Numeric variables A-Z |
| 2A68 | 2 | 2800 | Cursor position in memory |
| 2A6A | 2 | 3800 | End of memory |
| 2A6C | 2 | 00 | Number of HOME-protected bytes of video memory |
| 2A6E | 2 | 00 | Exit criteria for FOR-NEXT |
| 2A70 | 16 | 00 | X$ |
| 2A80 | 16 | 00 | Y$ |
| 2A91 | 2 | 00 | Stack for the current loop |
| 2A93 | 2 | 00 | Current line position (during FOR-NEXT) |
| 2A95 | 2 | 00 | BASIC pointer (during CALL and FOR-NEXT) |
| 2A97 | 2 | 00 | Location to DUMP from |
| 2A99 | 2 | 00 | 16*ARR$+16 |
| 2A9B | 2 | 00 | Address of NEXT variable |
| 2A9D | 2 | 2C3C | TAKE pointer |
| 2A9F | 2 | 00 | Current line position |
| 2AA1 | 2 | 00 | Register for active FOR-NEXT |
| 2AA3 | 2 | 00 | Temporary SP, during CALL |
| 2AA5 | 2 | 00 | Keyboard differentiator |
| 2AA7 | 3 | 00 | Seed for RND |
| 2AAA | 1 | 00 | Which pass through assembler (1 or 2) |
| 2AAC | 1 | 00 | ČĆŠŽ become CCSZ in print code for bit7=0 |
| 2AAC | 124  | 00 | Arithmetic accumulators (IX) |
| 2BA8 | 1 | 0C | Horizontal text position |
| 2BA9 | 3 | C9 | Command link |
| 2BAC | 3 | C9 | Video link |
| 2BAF | 1 | 00 | If bit 7=1, the clock is running |
| 2BB0 | 1 | 00 | Image scroll counter |
| 2BB1 | 1 | 00 | Image scroll flag |
| 2BB2 | 1 | 00 | How many rows to DUMP |
| 2BB3 | 1 | 00 | OPT during assembly |
| 2BB4 | 1 | 00 | REPT register |
| 2BB5 | 1 | 00 | Printer flag |
| 2BB6 | 125  | 00 | Buffer |
| 2C36 | 2 | 2C3A | BASIC start pointer |
| 2C38 | 2 | 2C3A | End of BASIC pointer |
| 2C3A | ?? | 00 | Program |

---

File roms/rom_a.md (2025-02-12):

Taken from here https://web.archive.org/web/20221228104534/https://www.tablix.org/~avian/galaksija/rom/rom1.html

<pre>
; ****************************************************************************
; * Assembly File Listing to generate 4K "ROM A" for Galaksija microcomputer *
; ****************************************************************************

; Introduction
; ************

; Disassembled from a binary ROM image and annotated by
; Tomaz Solc (tomaz.solc@tablix.org)
; using z80dasm (http://www.tablix.org/~avian/blog/articles/z80dasm)
; between September 2006 and September 2007

; The original assembly listing, complete with its lack of useful comments 
; is available at:

; http://www.galaksija.org/hr/index.php?title=Disasemblirani_ROM_A

; (Titled "MALI RACUNAR GALAKSIJA" by Voja Antonic 03.01.1984)

; $Id: rom1.asm,v 1.26 2007-09-23 12:06:17 avian Exp $

; "ROM A" contains basic operating system of Galaksija, which can be roughly
; separated into following sections:

;	o Initialization routines,
;	o video driver,
;	o keyboard scanning and simple terminal emulation,
;	o BASIC interpreter,
;	o RPN FP calculator and
;	o audio cassette load/save routines.

; This ROM is a work of art when you consider how tighly optimized for size 
; it is and a nightmare if you wish to completely understand or even modify 
; anything in it.

; This disassembly is a work in progress. Sections of the code remain 
; uncommented, however this file should assemble into a binary that is 
; identical to the original ROM image.

; Any contributions (for example additional comments on the code, patches, 
; etc.) are most welcome at tomaz.solc@tablix.org.

; Code sightseeing
; ****************

; A must-see list of 10 most-interesting parts of code:

; <a href="#l0098h">l0098h</a>	Part of video driver code used as ASCII string for 
;		BASIC interpreter.

; <a href="#l00a0h">l00a0h</a>	Part of video driver code used a 1.0 floating point
;		constant.

; <a href="#l0038h">l0038h</a>	Video driver code as a whole, tuned to one T cycle accuracy.

; <a href="#l038ch">l038ch</a>	A tutorial on how to use "ld" instructions instead of "jr"
; <a href="#l0393h">l0393h</a>	and save a few bytes in the process.
; <a href="#l0396h">l0396h</a>
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

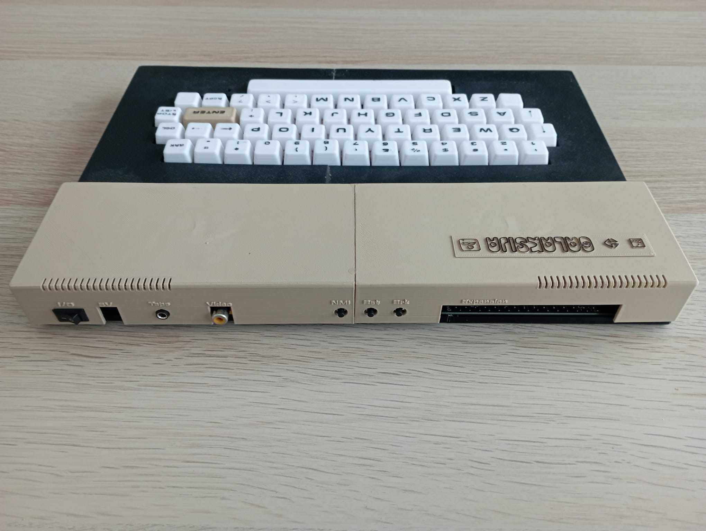
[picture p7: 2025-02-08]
case/photos/galaksija_back.jpg

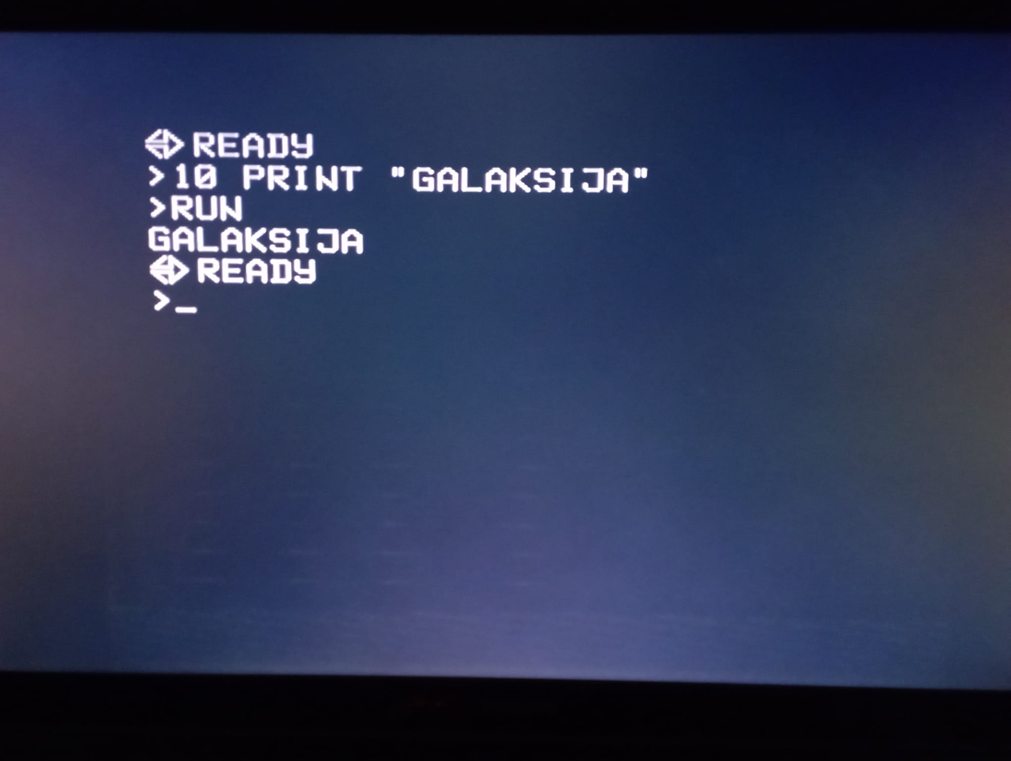
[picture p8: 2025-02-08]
case/photos/galaksija_screen.jpg

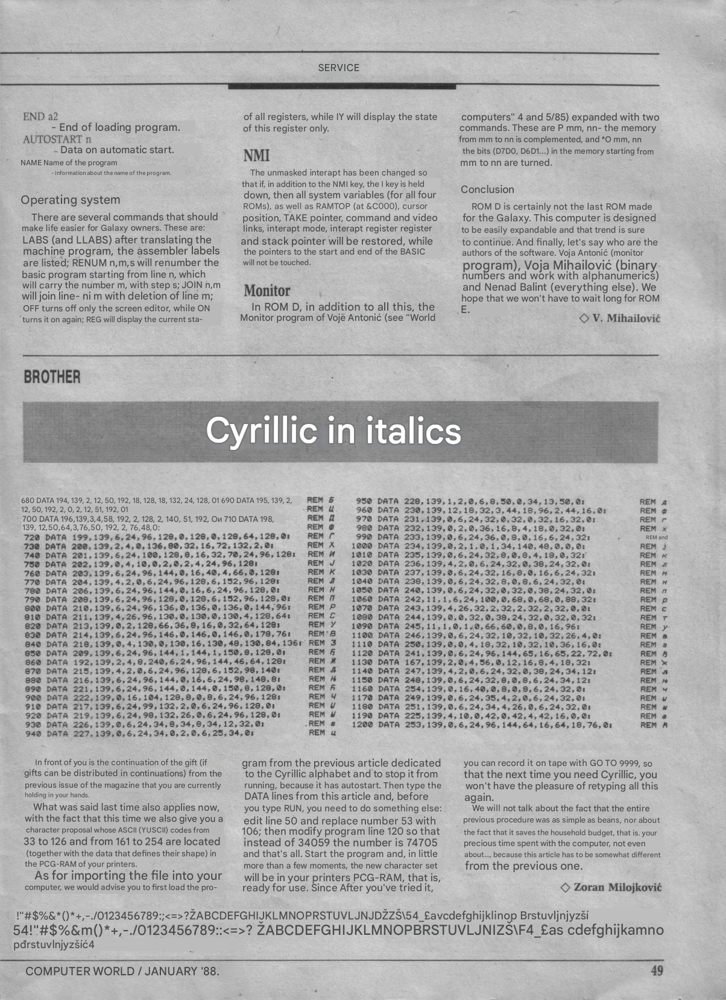
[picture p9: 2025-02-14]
roms/original/ROM_D/compworld_jan88_4th_rom_2.png

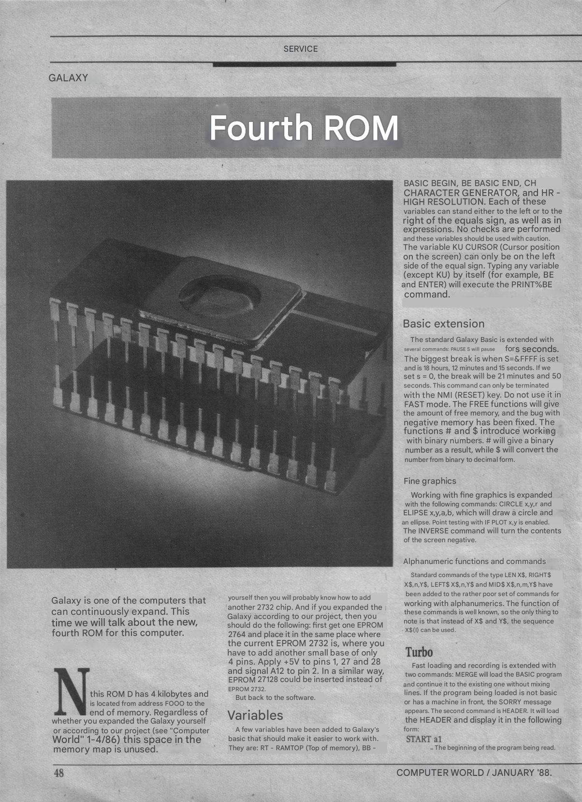
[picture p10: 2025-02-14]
roms/original/ROM_D/compworld_jan88_4th_rom.png

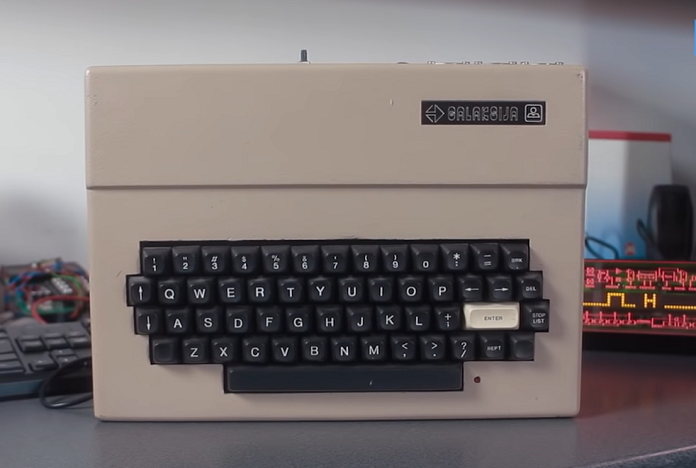
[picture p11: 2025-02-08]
case/misc/case_white.png

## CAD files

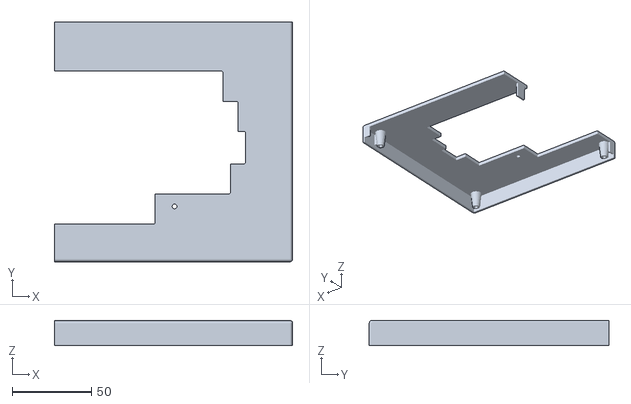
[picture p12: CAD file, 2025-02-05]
case/galaksija_case_top_2.stl
150.4 x 151.5 x 16.0

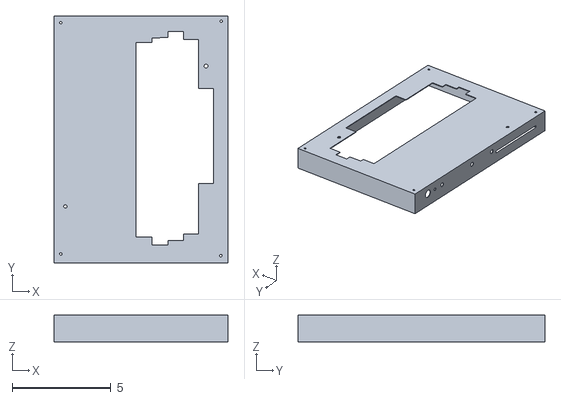
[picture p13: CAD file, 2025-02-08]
case/misc/galaksija.stl
8.78 x 12.5 x 1.34

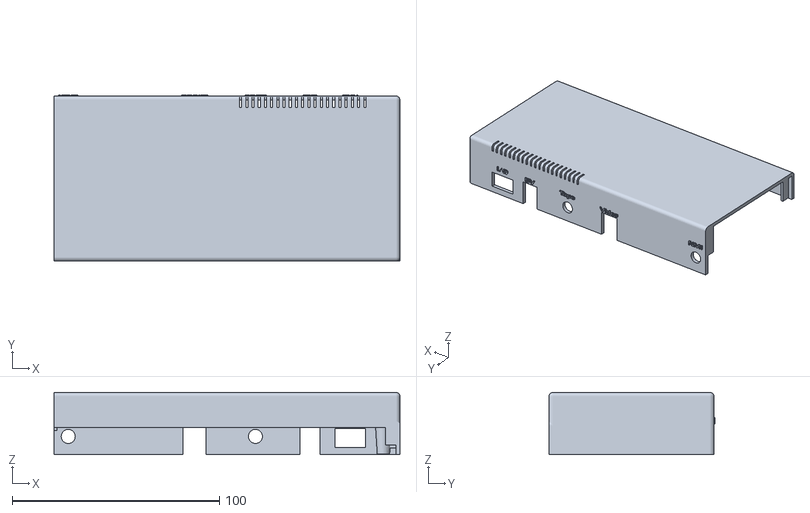
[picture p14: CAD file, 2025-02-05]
case/galaksija_case_top_4.stl
167.1 x 80.2 x 30.0

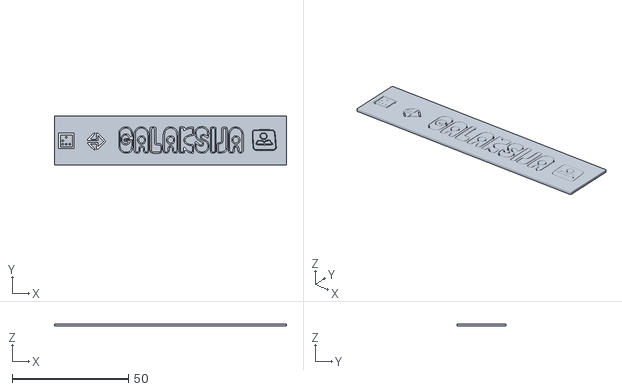
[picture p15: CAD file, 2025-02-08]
case/misc/logo_background.stl
100.0 x 21.2 x 1.00

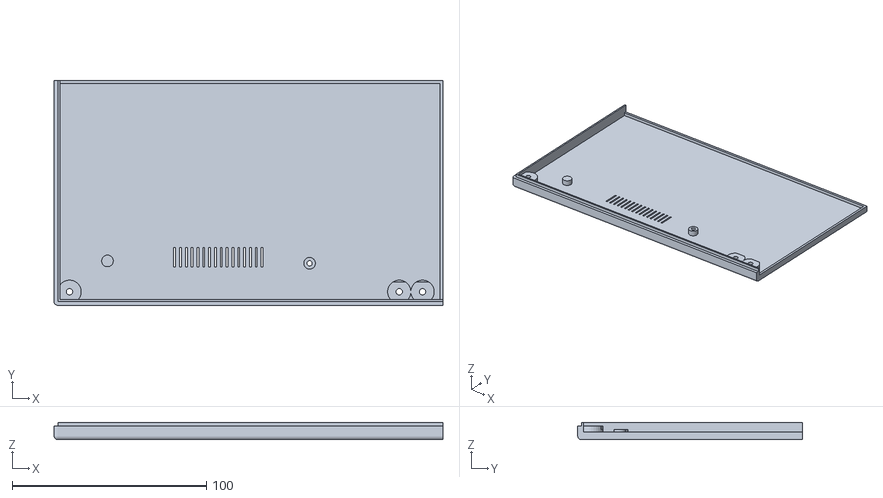
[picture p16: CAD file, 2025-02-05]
case/galaksija_case_base_1.stl
200.1 x 115.6 x 8.99

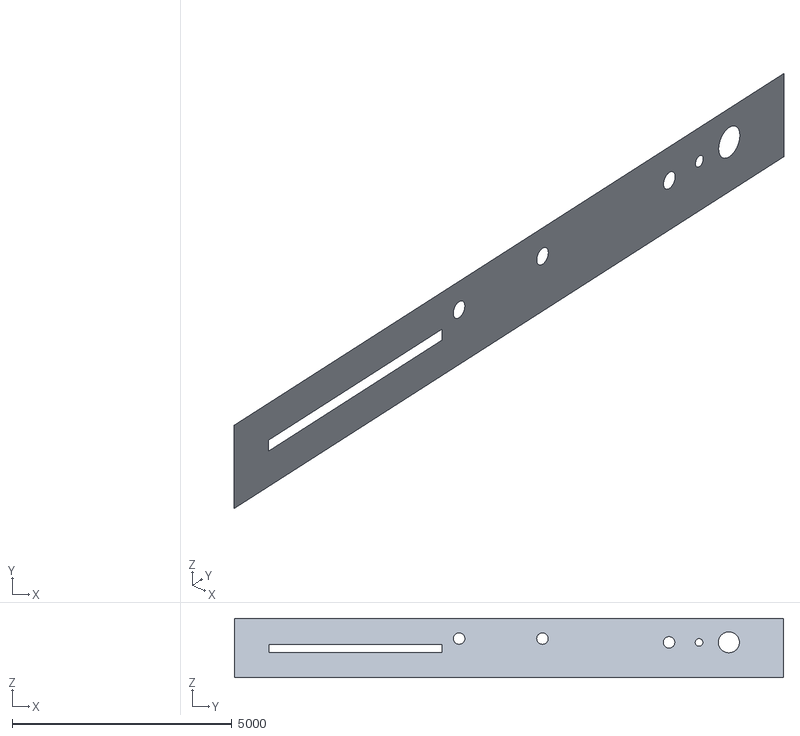
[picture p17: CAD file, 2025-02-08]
case/misc/back.stl
0 x 12485.0 x 1343.2

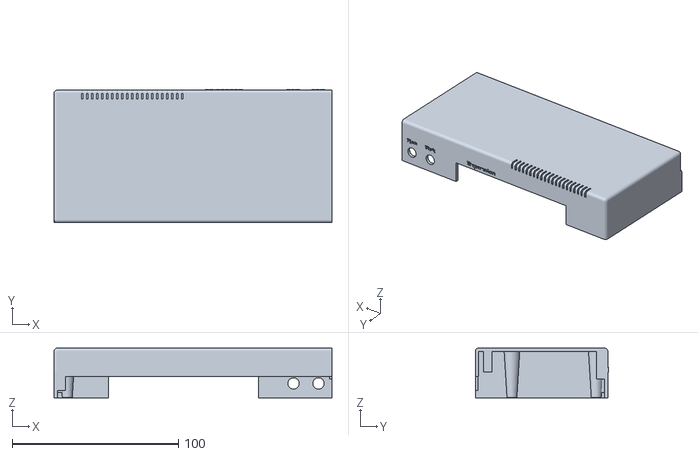
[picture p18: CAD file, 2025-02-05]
case/galaksija_case_top_3.stl
167.1 x 80.2 x 30.0

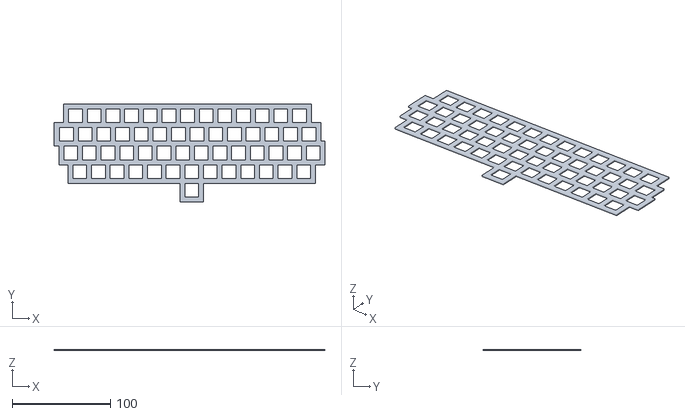
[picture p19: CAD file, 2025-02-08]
case/misc/galaksija_keyboard_plate.stl
276.0 x 100.0 x 1.50

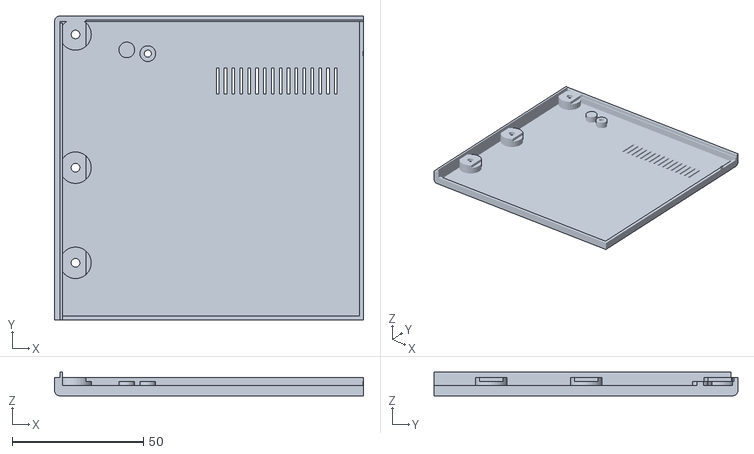
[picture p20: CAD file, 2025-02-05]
case/galaksija_case_base_3.stl
117.6 x 115.6 x 8.99

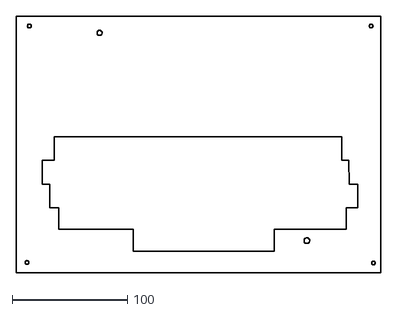
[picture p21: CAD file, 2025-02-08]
case/misc/top.dxf
317.1 x 223.1

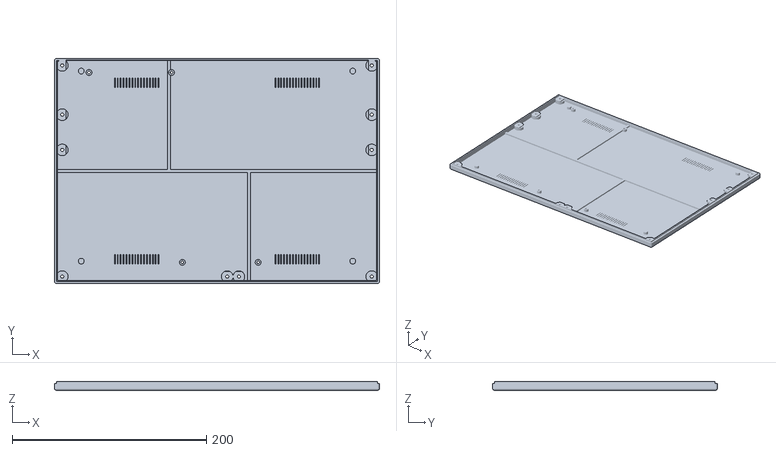
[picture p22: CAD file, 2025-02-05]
case/galaksija_case_base.stl
334.2 x 231.2 x 8.99

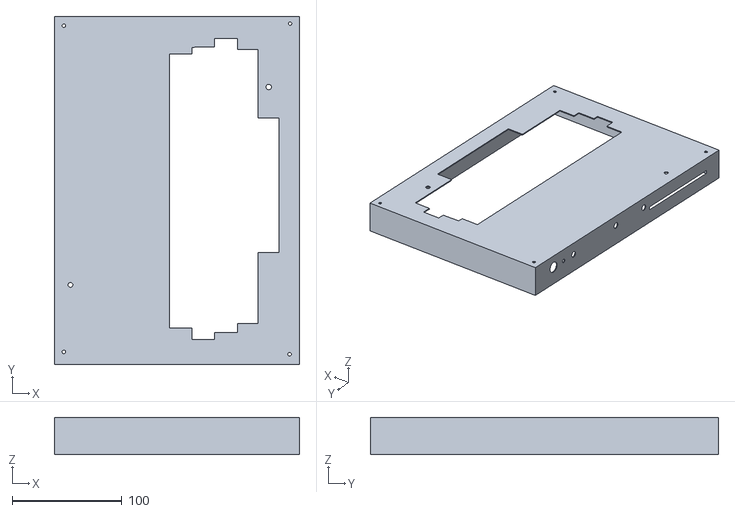
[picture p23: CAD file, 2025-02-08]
case/misc/galaksija_mm.stl
223.1 x 317.1 x 34.1

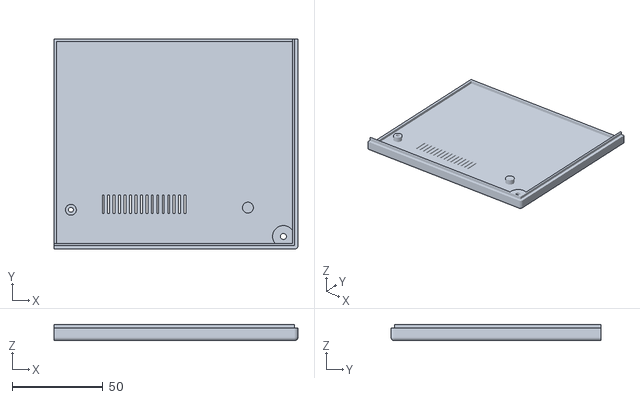
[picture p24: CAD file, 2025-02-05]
case/galaksija_case_base_2.stl
134.1 x 115.6 x 8.99

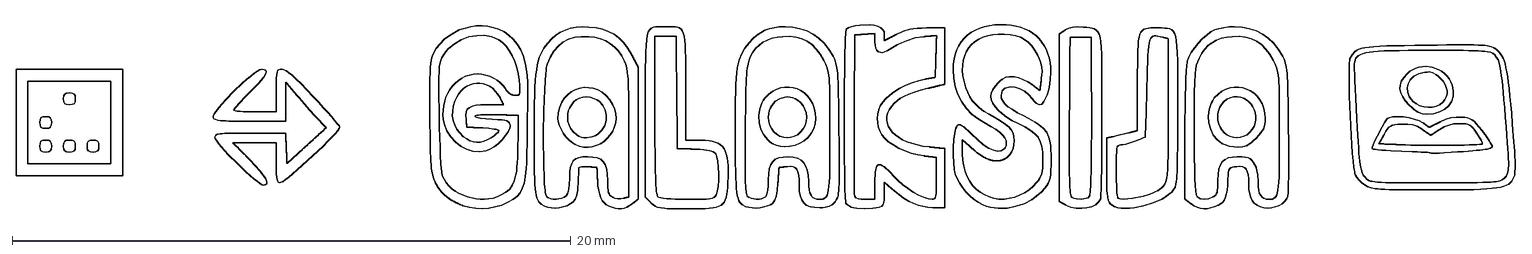
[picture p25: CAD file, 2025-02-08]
case/misc/logo3.dxf
53.7 x 7.07 mm

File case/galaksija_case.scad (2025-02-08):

/*
 Decription: Galaksija case
 Author: issalig
 Date: 06/02/25
 */

use("galaksija_keys.scad");

// measures taken from the pcb
$pcb_width = 310.24;
$pcb_height = 217.22;
$pcb_holes_dist = 77.928; // holes near space bar
$pcb_holes_x_off = 119.5; // offset from pcb origin
$pcb_holes_y_off = 9.65;
$pcb_hole_diam = 3;
$pcb_thickness = 1.6;

$case_width = $pcb_width + 20;
$case_height = $pcb_height + 10;
$case_base_deep = 5;
$case_top_deep = 12.5 + 1.5; // front part
$case_pcb_off_x = ($case_width - $pcb_width) / 2;
$case_pcb_off_y = $case_height - $pcb_height; // pcb until bottom
$case_height2 = $case_height / 3;
$case_top_deep2 = $case_top_deep + 8 + 6; // back part
$case_top_angle = 0;                      // 20;
$keyboard_frame_radius = 1;               // keep safe distance

$font_name = "GreenMountain3"; // https://www.whatfontis.com/FF_Green-Mountain-3.font

$base_vents_enabled = true;

// screw positions
$screws_width = $case_width - 12;
$screws_height = $case_height - 10;
$screws_metric = 3;

$thickness = 1;
$fillet_radius = 2; // 1.5
$fn_case = 30;
$fn = 50; //$fn_case;

$colortop = "gold";  //[0.15, 0.15, 0.15];
$colortop2 = "gold"; //[0.15, 0.15, 0.15];
$colorbase = "gold"; // [0.15, 0.15, 0.15];
$special_color = "#deb887";
$normal_color = [ 0.15, 0.15, 0.15 ];
$font_name = "GreenMountain3";

$top_nerves = 1;
$base_nerves = 1;

// position of the nerves and screw holes to make the sandwich
$base_nerve_x = 0.6; // relative nerve positions
$base_nerve_x2 = 0.35;
$base_nerve_y = 0.5;

$front_central_hole_x = 0.55; // use it with non symmetrical partitions to join base left with top right
$side_central_hole = 0.6;     // use it to join upper and lower parts

$top_nerve_x = 0.55; // for the keyboard part
$top_nerve_x2 = 0.5; // for the back part

$top_nerve_y = 2 / 3;

// logo
$logo_enabled = 1;          // show logo
$logo_text_enabled = false; // show font logo or galakisja original logo

// origin is pcb left bottom

// pcb from kicad export
module pcb()
{
	translate([ -532.5, -182.7, 0 ])
	import("galaksija_pcb.stl");

	// cube([$pcb_width, $pcb_height, $pcb_thickness]);
	translate([ $pcb_holes_x_off, $pcb_holes_y_off, -50 ])
	% cylinder(h = 100, d = $pcb_hole_diam);
	translate([ $pcb_holes_x_off + $pcb_holes_dist, $pcb_holes_y_off, -50 ])
	% cylinder(h = 100, d = $pcb_hole_diam);

	// led
	translate([ 247.5, 23, -50 ])
	% cylinder(h = 100, d = $pcb_hole_diam);

	// conn holes
	// 23.5, 204.92
	// 108.33, 204.92
	translate([ 23.5, 204.92, -50 ])
	% cylinder(h = 100, d = $pcb_hole_diam);
	translate([ 108.33, 204.92, -50 ])
	% cylinder(h = 100, d = $pcb_hole_diam);
}

// simple pcb mockup
module pcb_rectangle()
{
	cl = 0.3; // clearance
	translate([ -cl, -cl, 0 ]);
	cube([ $pcb_width + cl * 2, $pcb_height + cl * 2, $pcb_thickness + cl / 2 ]);
}

// for slanted back top
module chamfer_profile(width = 20, h = $case_height2 - $case_height, angle = 10)
{
	// h = r * cos(a);
	r = h / cos(angle);
	echo("h", h);
	y = r * sin(angle);
	x = r * cos(angle);

	rotate([ 0, 90, 0 ])
	linear_extrude(height = width)
#polygon(points = [ [ 0, 0 ], [ -x, 0 ], /*[-x/4, y/2],*/[ 0, y ] ]);
}

// holes for back connections
module back_connections()
{
	// data
	conn_deep = 14.5;
	translate([ -65.81 + $pcb_width / 2, $case_height / 2, $case_top_deep - conn_deep / 2 ])
	cube([ 90, 10, conn_deep ], center = true);
	// dc switch

	translate([ -$case_width / 2 + 22, $case_height / 2, $case_top_deep - 8 ])
	cube([ 14.6, 35, 9 ], center = true);

	// push nmi button
	translate([ -162 + $pcb_width / 2, $case_height / 2 + $fillet_radius, $case_top_deep - conn_deep / 2 - 1.5 ])
	rotate([ 90, 0, 0 ])
	cylinder(h = 20, d = 6.8, $fn = $fn_case);

	// push rst button
	translate([ -147 + $pcb_width / 2, $case_height / 2 + $fillet_radius, $case_top_deep - conn_deep / 2 - 1.5 ])
	rotate([ 90, 0, 0 ])
	cylinder(h = 20, d = 6.8, $fn = $fn_case);

	// push brk button
	translate([ -132 + $pcb_width / 2, $case_height / 2 + $fillet_radius, $case_top_deep - conn_deep / 2 - 1.5 ])
	rotate([ 90, 0, 0 ])
	cylinder(h = 20, d = 6.8, $fn = $fn_case);

	// video offset 87.25 - width 10.60
	// translate([-$case_width/2+$fillet_radius+87.2,$case_height/2,$case_top_deep-conn_deep/2])
	translate([ 87.25 - $pcb_width / 2, $case_height / 2, $case_top_deep - conn_deep / 2 ])
	cube([ 11, 10, conn_deep + 5 ], center = true);

	// dc offset 31.4 - width 9.2
	// translate([-$case_width/2+$fillet_radius+31.4,$case_height/2,//$case_top_deep-conn_deep/2])
	translate([ 31.4 - $pcb_width / 2, $case_height / 2, $case_top_deep - conn_deep / 2 ])
	cube([ 9.7, 10, conn_deep + 5 ], center = true);

	// audio offset 57.83 - width 11
	translate([ 57.83 - $pcb_width / 2, $case_height / 2 + $fillet_radius, $case_top_deep - conn_deep / 2 - 1.5 ])
	rotate([ 90, 0, 0 ])
	cylinder(h = 20, d = 6.8, $fn = $fn_case);

	// led
	translate([ $pcb_width / 2, -$pcb_height / 2 + $case_pcb_off_y / 2, 0 ])
	translate([ -247.5, 23, -$case_top_deep / 2 - $fillet_radius * 0 ])
	cylinder(h = 100, d = $pcb_hole_diam);
}

// text legends for back connections
module back_legends()
{

	// data legend
	translate([ 220 - $pcb_width / 2, $case_height / 2 + $fillet_radius, $case_top_deep - 14.5 - 0.5 - 1 ])
	rotate([ 270, 0, 0 ])
	// color([1,1,1])
	linear_extrude(0.5) text("Expansion", size = 3, font = $font_name, halign = "center", $fn = 50);

	// break legend
	translate([ -132 + $pcb_width / 2, $case_height / 2 + $fillet_radius, $case_top_deep / 2 - 7 - 1.5 ])
	rotate([ 270, 0, 0 ])
	// color([1,1,1])
	linear_extrude(0.5) text("Brk", size = 3, font = $font_name, halign = "center", $fn = 50);

	// reset legend
	translate([ -147 + $pcb_width / 2, $case_height / 2 + $fillet_radius, $case_top_deep / 2 - 7 - 1.5 ])
	rotate([ 270, 0, 0 ])
	// color([1,1,1])
	linear_extrude(0.5) text("Rst", size = 3, font = $font_name, halign = "center", $fn = 50);

	// nmi legend
	translate([ -162 + $pcb_width / 2, $case_height / 2 + $fillet_radius, $case_top_deep / 2 - 7 - 1.5 ])
	rotate([ 270, 0, 0 ])
	// color([1,1,1])
	linear_extrude(0.5) text("NMI", size = 3, font = $font_name, halign = "center", $fn = 50);

	// audio legend
	translate([ 57.83 - $pcb_width / 2, $case_height / 2 + $fillet_radius, $case_top_deep / 2 - 7 - 1.5 ])
	rotate([ 270, 0, 0 ])
	linear_extrude(0.5) text("Tape", size = 3, font = $font_name, halign = "center", $fn = 50);

	// video legend
	translate([ 87.25 - $pcb_width / 2, $case_height / 2 + $fillet_radius, $case_top_deep / 2 - 8 ])
	rotate([ 270, 0, 0 ])
	linear_extrude(0.5) text("Video", size = 3, font = $font_name, halign = "center", $fn = 50);

	// dc legend
	translate([ 31.4 - $pcb_width / 2, $case_height / 2 + $fillet_radius, $case_top_deep / 2 - 8 ])
	rotate([ 270, 0, 0 ])
	linear_extrude(0.5) text("5V", size = 3, font = $font_name, halign = "center", $fn = 50);

	// switch legend
	translate([ -$case_width / 2 + $fillet_radius + 20, $case_height / 2 + $fillet_radius, $case_top_deep / 2 - 8 ])
	rotate([ 270, 0, 0 ])
	linear_extrude(0.5) text("I/O", size = 3, font = $font_name, halign = "center", $fn = 50);
}

// logo using font from keyboard
module logo()
{
	if ($logo_text_enabled)
	{
		translate([ $case_width / 2 - 37, $case_height / 2 - 30, -$case_top_deep2 / 2 + 0.5 ])
		rotate([ 0, 180, 0 ])
		linear_extrude(0.5) text("GALAKSIJA", size = 4.5, font = $font_name, halign = "center", $fn = 50);

		translate([ $case_width / 2 - 37, $case_height / 2 - 30 - 6, -$case_top_deep2 / 2 + 0.5 ])
		rotate([ 0, 180, 0 ])
		linear_extrude(0.5) text("MIKRO RAČUNAR", size = 2.8, font = $font_name, halign = "center", $fn = 50);
	}
}

module top_front()
{
	angle = 0; // TODO fix it to work with angles

	// logo
	if ($logo_enabled)
	{
		color($normal_color) translate(
		    [ -$case_width / 2 + 65 + 200, $case_height / 2 - 30, -$case_top_deep2 / 2 - $fillet_radius + 2 - 3 ])
		rotate([ 0, 180, 0 ])
		// scale([1,1,2])
		// ImageToStl.com
		import("galaksija_logo.stl");
		// import("galaksija_logo_plate.stl");
		/*
		scale([1, 1, 0.1])
	  surface(file = "smiley.png", center = true, invert = true);

		*/
	}

	// main body
	difference()
	{
		minkowski()
		{
			translate([ 0, 0, $case_top_deep / 2 ])
			// cube([$case_width, $case_height, $case_top_deep], center = true );

			// slanted middle

			difference()
			{
				cube([ $case_width, $case_height, $case_top_deep ], center = true);
				translate([ -$case_width / 2, -$case_height / 2, -$case_top_deep / 2 ])
				chamfer_profile(width = $case_width, h = $case_top_deep, angle = angle);
			}

			sphere(r = $fillet_radius, $fn = $fn_case);
		}
		// remove inner part
		translate([ 0, 0, ($case_top_deep + $fillet_radius) / 2 ])
		// cube([$case_width, $case_height, $case_top_deep+$fillet_radius], center = true );
		difference()
		{
			angle = 0;
			cube([ $case_width, $case_height, $case_top_deep ], center = true);
			translate([ -$case_width / 2, -$case_height / 2, -$case_top_deep / 2 ])
			chamfer_profile(width = $case_width, h = $case_top_deep, angle = angle);
		}
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

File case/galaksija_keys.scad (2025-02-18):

/*
 Decription: Keycaps for galaksija keyboard using cherry switches
 Author: issalig
 Date: 06/02/25

 Keytop is flat (rounded surfaces are not nice for FDM printers)
 Print it without any support.
*/
/*
 Letter options
  - A. Paint the letters with a permanent marker.
  - B. Print them and stick them onto the keys. ($text_enabled = false)
  - C. Change the filament color and add the following to your gcode.

;ADD BEFORE THE LAST AFTER_LAYER_CHANGE

;COLOR_CHANGE BEGIN
;ADD SAFETY HEIGHT
G1 Z17 F9000
;STOP FOR CHANGE
M0
;EXTRUDE MATERIAL
G1 E450 F500
;STOP TO CLEAN OR WHATEVER
M0
;RETURN TO HEIGHT
G1 Z10.8 F9000
;COLOR_CHANGE_END

;AFTER_LAYER_CHANGE

*/

$font_name = "GreenMountain3"; // https://www.whatfontis.com/FF_Green-Mountain-3.font
$font_color = [ 0, 0, 0 ];
$special_key_color = "#deb887";
$normal_key_color = [ 0.95, 0.95, 0.95 ];
$text_enabled = true; // characters on keys
$key_space = 19;      // space between keys in pcb

$fn_keys = 40;
$fn_text = 20;
$fn = $fn_keys;

$key_thickness = 1;

$font_size = 6;
$font_size_medium = 4;
$font_size_small = 3;
$text_height = 0.2 * 2; // 0.4 better for FDM

// supports
$stem_support = false; // in case there are adhesion problems
$grid_support = false; // if you plan to print it all together

// main key function
module key(width = 18, height = 18, deep = 7.2, x_diff = 5.2, y_diff = 4.5, z_diff = 0, slant = 0, y_off = 2,
           rounded_corner = 0.5, rounded_corner2 = 3,  thickness = $key_thickness, upper_bevel_radius = 0, slant = 0, base_height = 0.001)
{
    //rounded_corner is radius on corner at bottom
    //rounded_corner2 is radius on corner at top
    
	deep2 = deep + z_diff;
	w_up = width - x_diff; // upper width

	// compute angle for upper side
	ang = atan2(deep - deep2, w_up) + slant;

	// keycap is the difference of inner and outer shell
	// inner and outher shells are hulls from upper and bottom countours
	{
		difference()
		{
			// outer
			hull()
			{
				// bottom side
				translate([ 0, 0, 0.5 * 0 ]) //????  //remember to lower it later by -0.5
				minkowski()
				{
					cube([ width - 2 * rounded_corner, height - 2 * rounded_corner, base_height ], center = true);
					cylinder(r = rounded_corner, h = 0.001, $fn = $fn_keys);
				}

				// upper side
				translate([ 0, y_off, min(deep, deep2) + abs(deep - deep2) / 2 - upper_bevel_radius ])
				// min(h_front[row], h_back[row]) + abs(h_front[row] - h_back[row]) / 2  - upper_bevel_radius])

				rotate([ -ang, 0, 0 ])
				// fillet
				minkowski()
				{
					// rounded corners
					minkowski()
					{
						cube(
						    [
							    width - x_diff - 2 * rounded_corner2 - 2 * upper_bevel_radius,
							    height - y_diff - 2 * rounded_corner2 - 2 * upper_bevel_radius, 0.001
						    ],
						    center = true);
						cylinder(r = rounded_corner2, h = 0.001, $fn = $fn_keys);
					}
					sphere(r = upper_bevel_radius, $fn = $fn_keys);
				}
			}

			// inner is a hull of bottom and upper
			hull()
			{
				translate([ 0, 0, -0.01 ]) // needed it to make the hole

				// bottom
				minkowski()
				{
					cube([ width - 2 * thickness - rounded_corner, height - 2 * thickness - rounded_corner, 0.001 ],
					     center = true);
					cylinder(r = rounded_corner / 2, h = 0.001, $fn = $fn_keys);
				}

				// upper
				translate([ 0, y_off, min(deep, deep2) - max(1 * thickness, upper_bevel_radius) ])
				// translate([ 0, 2 * thickness, min(h_front[row], h_back[row]) - 1 * thickness ])
				rotate([ -ang, 0, 0 ])

				minkowski()
				{
					// inner rounded corner is halved
					cube(
					    [
						    width - x_diff - 2 * thickness - rounded_corner2 - rounded_corner,
						    height - y_diff - 2 * thickness - rounded_corner2 - rounded_corner, 0.001
					    ],
					    center = true);
					cylinder(r = rounded_corner2 / 2, h = 0.001, $fn = $fn_keys);
				}
			}
		}
	}

	// grid support
	if ($grid_support)
	{
		ls = 6;

		// right
		translate([ width / 2, 0, 1 / 2 ])
#cube([ 2, 1, 1 ], center = true);
		// down
		translate([ -1.5, -height / 2, 1 / 2 ])
		rotate([ 0, 0, 90 ])
#cube([ 2, 1, 1 ], center = true);
	}
}

// normal key, uses key module and adds stem
module key_galaksija()
{
	// key
	width = 18;
	height = 18;
	x_diff = 3;
	y_diff = 3;
	y_off = y_diff / 2 - 1;
	deep = 10.5;
	key(width = width, height = height, x_diff = x_diff, y_diff = y_diff, y_off = y_off, deep = deep,
	    upper_bevel_radius = 1, rounded_corner = 1.5, base_height = 0.001, thickness = $key_thickness);

	// stem
	deep_stem = deep - 0.5;
	off_y_stem = 0;
	translate([ 0, 0, off_y_stem ])
	cherry_stem(deep = deep_stem - off_y_stem, cross_thickness = 1.25);
}

// cherry stem dimensions
// https://telcontar.net/KBK/Cherry/images/MX/Cherry_8_mm_mount.svgz
module cherry_stem(cross_thickness = 1.25, cross_width = 5, cross_deep = 4.1, outer_width = 6.85, outer_height = 4.5,
                   deep = 20)
{
	// for dust switches, non tested!!!
	// outer_width = 5.7;
	// outer_height = 4;

	// trapezoidal upper ending
	hull()
	{
		translate([ 0, 0, deep ])
		cube([ outer_width * 1.5, outer_height * 1.5, 0.1 ], center = true);
		translate([ 0, 0, cross_deep + 1 ])
		cube([ outer_width, outer_height, 0.1 ], center = true);
	}

	// stem body
	difference()
	{
		translate([ 0, 0, (cross_deep + 1.5) / 2 ])
		cube([ outer_width, outer_height, cross_deep + 1.5 ], center = true);

		// cross is made with 2 crossing cubes
		translate([ 0, 0, cross_deep / 2 ])
		cube([ cross_width, cross_thickness, cross_deep ], center = true);
		translate([ 0, 0, cross_deep / 2 ])
		cube([ cross_thickness, cross_width, cross_deep ], center = true);
	}

	// printing support
	if ($stem_support)
	{
		ls = 6;

		// left right
		translate([ ls, 0, 0.4 / 2 ])
		cube([ ls, 0.4, 0.4 ], center = true);
		translate([ -(ls), 0, 0.4 / 2 ])
		cube([ ls, 0.4, 0.4 ], center = true);

		translate([ 1.5, ls - 1, 0.4 / 2 ])
		rotate([ 0, 0, 90 ])
		cube([ ls, 0.4, 0.4 ], center = true);
		translate([ -1.5, ls - 1, 0.4 / 2 ])
		rotate([ 0, 0, 90 ])
		cube([ ls, 0.4, 0.4 ], center = true);

		translate([ 1.5, -ls + 1, 0.4 / 2 ])
		rotate([ 0, 0, 90 ])
		cube([ ls, 0.4, 0.4 ], center = true);
		translate([ -1.5, -ls + 1, 0.4 / 2 ])
		rotate([ 0, 0, 90 ])
		cube([ ls, 0.4, 0.4 ], center = true);
	}
}

// enter key is 2u
module key_enter_galaksija(u = 2)
{
	height = 18;
	width = 19 * u - 1; // 18.5*u-0.2;
	deep = 10.5;
	x_diff = 3;
	y_diff = 3;
	y_off = y_diff / 2 - 1;

	key(width = width, height = height, x_diff = x_diff, y_diff = y_diff, y_off = y_off, deep = deep,
	    upper_bevel_radius = 1, rounded_corner = 1.5, base_height = 0.001, thickness = $key_thickness);

	deep_stem = deep - 0.5;
	off_y_stem = 0;

	// central stem is a little bit displaced to the right. measured in pcb
	translate([ 0.24, 0, off_y_stem ])
	cherry_stem(deep = deep_stem - off_y_stem, cross_thickness = 1.25);
}

// space is 8u
module key_space_galaksija(u = 8)
{
	height = 19 - 1;
	width = 19 * u - 1; // 18.5*u-0.2;
	deep = 10.5 + 0.5;  // space is slightly higher than normal key
	x_diff = 3;
	y_diff = 3;
	y_off = y_diff / 2 - 1;

	hole_dist = 77.928 + 14;

	echo("Spacebar width:", width * u - 0.2);

	// space is thicker than normal keys
	key(width = width, height = height, x_diff = x_diff, y_diff = y_diff, y_off = y_off, deep = deep,
	    upper_bevel_radius = 1.75, rounded_corner = 1.5, base_height = 0.001, thickness = $key_thickness);

	deep_stem = deep - 0.5;
	off_y_stem = 0;

	// central stem
	translate([ 0, 0, off_y_stem ])
	cherry_stem(deep = deep_stem - off_y_stem, cross_thickness = 1.25);
	// side stems for retainers
	translate([ hole_dist / 2, 0, off_y_stem ])
	cherry_stem(deep = deep_stem - off_y_stem, cross_thickness = 1.25);
	translate([ -hole_dist / 2, 0, off_y_stem ])
	cherry_stem(deep = deep_stem - off_y_stem, cross_thickness = 1.25);

	// centering tubes
	translate([ hole_dist / 2 + 1 + 10, 0, off_y_stem ])
	difference()
	{
		cylinder(h = deep, d = 6.4);
		cylinder(h = deep - 4, d1 = 4.9, d2 = 4);
	}
	translate([ -(hole_dist / 2 + 1 + 10), 0, off_y_stem ])
	difference()
	{
		cylinder(h = deep, d = 6.4);
		cylinder(h = deep - 4, d1 = 4.9, d2 = 4);
	}

	translate([ 25, 0, off_y_stem ])
	difference()
	{
		cylinder(h = deep, d = 6.4);
		cylinder(h = deep - 4, d1 = 4.9, d2 = 4);
	}
	translate([ -25, 0, off_y_stem ])
	difference()
	{
		cylinder(h = deep, d = 6.4);
		cylinder(h = deep - 4, d1 = 4.9, d2 = 4);
	}
}

// text on keys
module text_galaksija(text = "A", deep = 10.5, font_size = $font_size, font_name = "GreenMountain3",
                      font_height = $text_height)
{
  
	if (($text_enabled))
	{

		y_offset = 0.5;

		translate([ 0, y_offset, deep ])
		color($font_color) linear_extrude(height = font_height)
		{
			text(text, size = font_size, font = font_name, halign = "center", valign = "center", $fn = $fn_text);
		}
	}
}
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

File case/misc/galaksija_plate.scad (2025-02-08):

//generate top.dxf
//top
//projection(cut = false)
//rotate([0,0,-90])
//translate([-4-223,43,0])
//import("galaksija_mm.stl");

//generate keyboard_plate.dxf
projection()
//rotate([0,90,0])
translate([0,0,-0.5])
//linear_extrude(height = 5, center = true, $fn = 16)
{
import("galaksija_keyboard_plate.stl");
}

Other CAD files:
case/galaksija_case_base_4.stl
case/misc/logo.stl
case/galaksija_case_top_1.stl
case/misc/galaksija_logo_plate.stl
case/galaksija_keys.dxf
case/galaksija_keys_and_contour.dxf
case/galaksija_keys_contour.dxf
case/misc/galaksija_keyboard_plate.dxf

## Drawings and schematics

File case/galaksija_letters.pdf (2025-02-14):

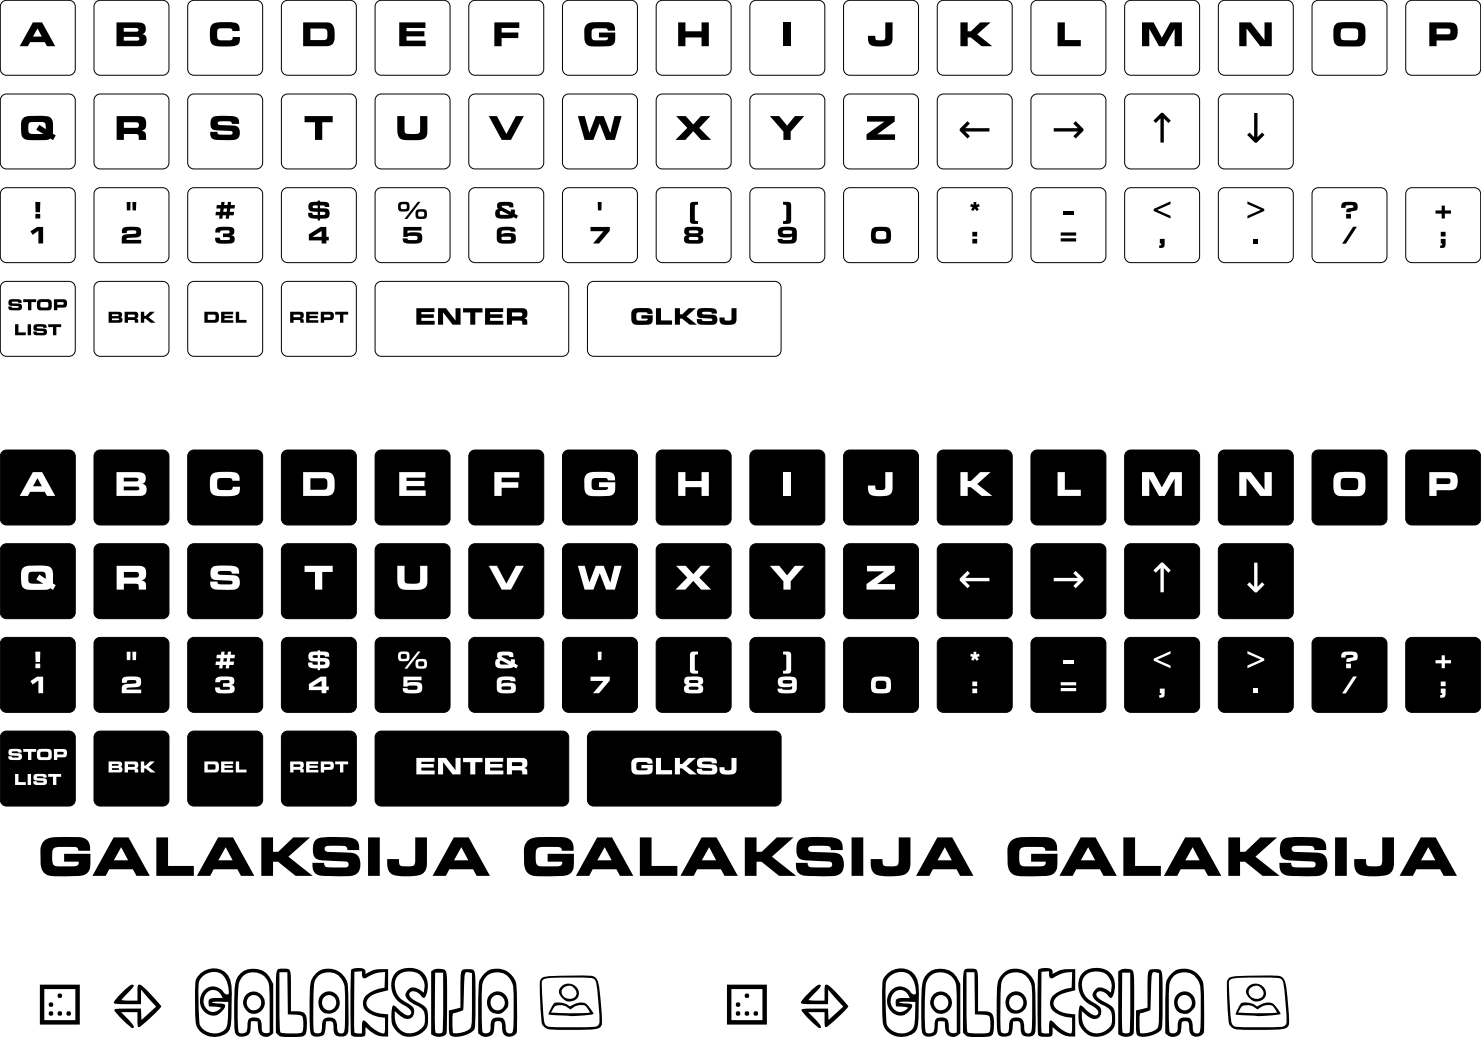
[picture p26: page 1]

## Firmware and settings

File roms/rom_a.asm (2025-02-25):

; ****************************************************************************
; * Assembly File Listing to generate 4K "ROM A" for Galaksija microcomputer *
; ****************************************************************************

; Introduction
; ************

; Disassembled from a binary ROM image and annotated by
; Tomaz Solc (tomaz.solc@tablix.org)
; using z80dasm (http://www.tablix.org/~avian/blog/articles/z80dasm)
; between September 2006 and September 2007

; The original assembly listing, complete with its lack of useful comments 
; is available at:

; http://www.galaksija.org/hr/index.php?title=Disasemblirani_ROM_A

; (Titled "MALI RACUNAR GALAKSIJA" by Voja Antonic 03.01.1984)

; $Id: rom1.asm,v 1.26 2007-09-23 12:06:17 avian Exp $

; "ROM A" contains basic operating system of Galaksija, which can be roughly
; separated into following sections:

;	o Initialization routines,
;	o video driver,
;	o keyboard scanning and simple terminal emulation,
;	o BASIC interpreter,
;	o RPN FP calculator and
;	o audio cassette load/save routines.

; This ROM is a work of art when you consider how tighly optimized for size 
; it is and a nightmare if you wish to completely understand or even modify 
; anything in it.

; This disassembly is a work in progress. Sections of the code remain 
; uncommented, however this file should assemble into a binary that is 
; identical to the original ROM image.

; Any contributions (for example additional comments on the code, patches, 
; etc.) are most welcome at tomaz.solc@tablix.org.


; Code sightseeing
; ****************

; A must-see list of 10 most-interesting parts of code:

; l0098h	Part of video driver code used as ASCII string for 
;		BASIC interpreter.

; l00a0h	Part of video driver code used a 1.0 floating point
;		constant.

; l0038h	Video driver code as a whole, tuned to one T cycle accuracy.

; l038ch	A tutorial on how to use "ld" instructions instead of "jr"
; l0393h	and save a few bytes in the process.
; l0396h 

; l0018h	A function that gets its arguments from bytes in ROM that 
;		follow its call.

; l0d2ah	Increasing randomness of pseudo-random generator by changing 
;		the seed after some keys are pressed.

; l0d70h	One look-up table nested inside unused space of another.

; l06cfh	DOT - a true multi-purpose function: query, set or reset a 
;		pseudo-graphic pixel or turn real time clock on or off
;		all in one block of code.

; l0e58h	Record one additional garbage byte at the end of an audio tape
;		because it saves one "jr" instruction in ROM.

; l0fffh	One spare byte for future expansions.


; About the latch
; ***************

; A 6-bit register (called "latch" in the original documentation) can be 
; accessed on all memory addresses that can be written in binary as

; 0 0 1 0  0 x x x  x x 1 1  1 x x x  
; (for example 207fh as used in VIDEO_INT)

; The content is write-only. A read from these addresses will return an 
; unspecified value.

; Individual bits have the following meaning:
;
;  7	Clamp RAM A7 to one (1 disabled, 0 enabled)
;  ---
;  6    Cassette port output bit 0
;  ---
;  5    Character generator row bit 3
;  ---
;  4	Character generator row bit 2
;  ---
;  3	Character generator row bit 1
;  ---
;  2	Character generator row bit 0
;	Cassette port output bit 1
;  ---
;  1	Unused
;  ---
;  0	Unused

;  Character generator row bits hold the current row of the character being
;  drawn to the screen.

;  Cassette port is high if both output bits are 1, low if both are 0 and
;  zero if one bit is 1 and one is 0.

;  Bit 7 forces RAM address line A7 to one. This is required because the top
;  bit of the R register never changes (only bottom 7 bits are incremented
;  during each opcode).


; issalig 25/02/2025
; These definitions allow to select different versions of the ROM
; can be overwritten externally with sjasmplus -DROM_A_VERSION=29 -DROM_B_AUTOSTART=1 rom_a.asm

	IFNDEF ROM_A_VERSION
	DEFINE ROM_A_VERSION 28		; 28 for no autostart, 29 for autostart
	ENDIF

	IFNDEF ROM_B_AUTOSTART
	DEFINE ROM_B_AUTOSTART 0	; 0 = no autostart, 1 = autostart
	ENDIF

; ROM A is mapped to memory addresses from 0000h to 0fffh

	org	00000h


; 'START'
; =======
; At power on Z80 starts to execute code here. Interrupt mode is set to 0.

;; START
l0000h:
	di		;0000   Disable interrupts
	sub a		;0001	Clear accumulator
	jp l03dah	;0002	Jump forward to START_2, the remainder of
			;	the initialization code.

; 'EVALUATE NEXT INTEGER ARGUMENT'
; ================================
; Evaluate an integer expression at DE behind a ASCII comma. If comma is not
; found, jump to WHAT_RST.

;; EVAL_INT_EXP_NEXT
l0005h:
	rst 18h		;0005	Call READ_PAR
	db ','		;0006	
	db l0034h-$-1	;0007	Jump to WHAT_RST if there is no next argument
			;	at DE.

; 'EVALUATE INTEGER EXPRESSION'
; =============================
; Evaluate an integer expression at DE and return the result in HL.

;; EVAL_INT_EXP
l0008h:
	call l0ab2h	;0008	Call EVAL_EXPRESSION
	jp l0a6dh	;000b	Jump to FP_TO_INT and return.

; 'FAST MODE'
; ===========
; Disable video interrupt.

;; FAST
l000eh:	
	di		;000e
	ret		;000f	

; 'COMPARE HL WITH DE'
; ====================
; This function compares HL with DE register pair and sets C and Z flags 
; accordingly

; Parameters:
;	DE, HL: values to be compared
; Returns:
;	C, Z flag
; Destroys:
;	A, all other flags

;; CMP_HL_DE
l0010h:
	ld a,h		;0010	Load H into A
	cp d		;0011	Compare with D
	ret nz		;0012	Return if not equal
	ld a,l		;0013	Load L into A
	cp e		;0014	Compare with E
	ret		;0015	Return

; 'SLOW MODE'
; ===========
; Enable video interrupt.

;; SLOW
l0016h:
	ei		;0016
	ret		;0017

; 'READ PARAMETER'
; ================
; This function reads the byte following the calling "rst" instruction and
; returns to a different location (specified with the second following byte) 
; if the byte doesn't match the first non-space character in the string pointed 
; to by DE register.

; Example:
;	rst 18h		; 0005
;	db ','		; 0006
;	db 02ch		; 0007
;       ...		; 0008

; This compares the first non-space character in DE with ASCII comma ',' 
; ignoring any leading space. If it matches, READ PARAMETER returns to the next
; instruction following the two bytes (at 0008h). If not, it adds 02ch to this
; return address (in this case it would return to 0034h). In the first case
; DE is also incremented to account for the matched byte.

; In pseudo-code:
;
; If (**SP) == (EAT_SPACE(DE)) Then
;	*SP=*SP+2
; 	DE=DE+1
; Else
;	*SP=*SP+2+(*(*SP+1))		
; End

; Parameters:
;	DE: Pointer a string.
; Returns:
;	DE: Skips leading space and increments DE, if there is a match.
;	A: First non-space character in DE.
;	Zf: Set if character matches, reset if not.
; Destroys: 
;	flags.

;; READ_PAR
l0018h:
	ex (sp),hl	;0018	Load a pointer from top of stack into HL

	call l0105h	;0019	Call EAT_SPACE	      

	cp (hl)		;001c	Compare memory pointed by HL with A
	jp l0194h	;001d	Jump to the rest of the function at READ_PAR_2
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

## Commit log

2025-02-08 misc files for case
    [back.stl, galaksija.stl, galaksija_keyboard_plate.dxf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]
2025-02-08 docs and more
    [galaksija_case.scad, galaksija_keys.scad]
2025-02-18 more rounded keys as original
    [galaksija_keys.scad]
